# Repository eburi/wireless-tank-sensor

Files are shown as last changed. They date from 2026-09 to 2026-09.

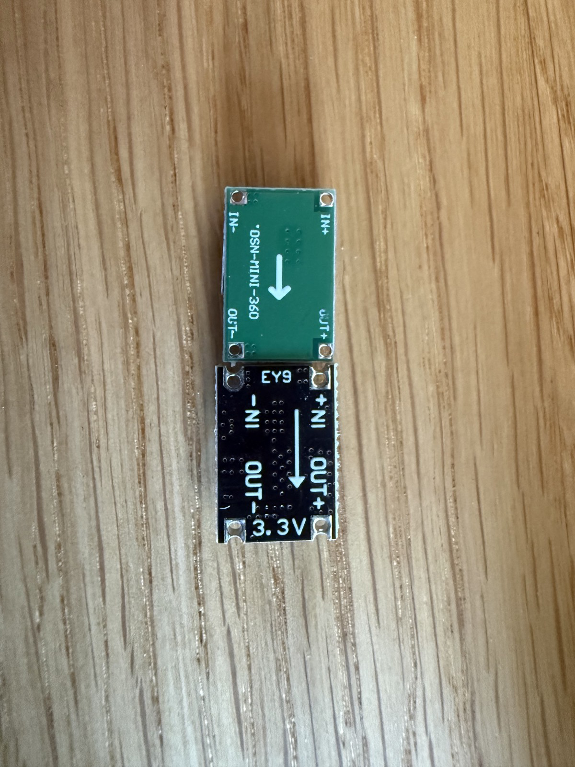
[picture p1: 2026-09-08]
hardware/kali-tank-sensor-v3/doc/dcdc-variants-side-by-side.jpg

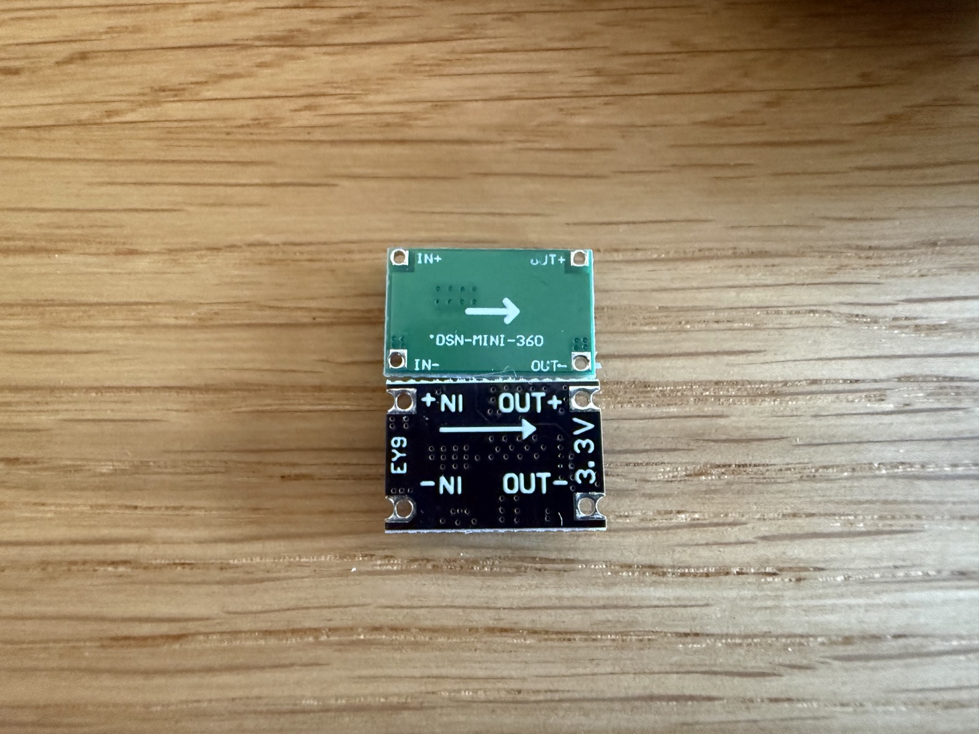
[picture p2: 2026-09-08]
hardware/kali-tank-sensor-v3/doc/dcdc-variants-stacked.jpg

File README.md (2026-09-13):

# 🚤 wireless-tank-sensor














A sealed, potted, maintenance-free **water tank level sensor** for boats (or caravans,
cabins, anything with a resistive tank sender and a 12 V bus). It runs on a
**Seeed XIAO ESP32-C3**, measures the plain old resistive float sender, works out the
level itself, and shouts the result at **Home Assistant** over **Bluetooth (BTHome v2)**.

You run **two wires** (12 V and ground) to the tank. That's it. No gauge, no Wi-Fi at
the tank, no app, no cloud. Everything else happens in the Home Assistant box you
already have on board.

> **TL;DR** — three ESPHome [external components](https://esphome.io/components/external_components/)
> (`bthome_beacon`, `tank_level`, `ota_beacon`) plus ready-to-copy example configs.
> Read on for the story, the wiring, and the lessons that cost me a night of sleep.

---

## 🧭 The backstory

When I bought the boat, she came with a set of tank sensors and a very confident
ship's manual. What she did *not* come with were the **analog gauges** those sensors
once fed — a previous owner had removed them at some point in the last geological era,
leaving behind a few dangling wires, a hole in the panel, and a gap in my
understanding of how much fresh water was actually left.

So for the first seasons the "fresh water level" was determined by a highly advanced
algorithm: *the pump starts sounding sad → tank is empty*. This works, in the sense
that a smoke alarm "works" as an oven timer.

Eventually I ripped out the corroded old senders and dropped in **cheap standard
resistive float senders** (~10 Ω to ~180 Ω, the kind every chandlery sells for the
price of a round of drinks). Then came the question: what to connect them to? Buying
new analog gauges felt like installing a fax machine. Buying a "smart" marine tank
monitor felt like paying for a fax machine with a subscription.

Meanwhile there was already a **Home Assistant** box on board, quietly collecting
temperatures, battery voltages and GPS fixes. It has Bluetooth. Bluetooth reaches the
tank locker. You can see where this is going.

The result is this repo: a tiny board that sits by the tank, needs only 12 V, sleeps
almost all the time, wakes up every ten seconds to measure the sender, and broadcasts
the level as a BTHome advertisement. Home Assistant picks it up like any other BTHome
gadget — no pairing, no integration to install, no IP address. The Wi-Fi radio is
switched off and only wakes for firmware updates, because on a boat the Wi-Fi is the
first thing you turn off to save power.

Now the fresh water tank shows up on the dashboard next to the batteries, the "tank
almost empty" sensor can nag me on my phone, and the pump has stopped sounding sad
unexpectedly. Mostly.

---

## ✨ What it does

| | |
|---|---|
| 📡 **BTHome v2 over BLE** | Home Assistant auto-discovers the sensor. Level (%), volume (L), raw sender resistance (Ω) and an *almost empty* problem flag, all in one 31-byte advertisement. |
| 😴 **Deep sleep duty cycle** | Wake → power the measurement chain → sample for ~2.5 s → advertise → sleep 10 s. The sender, the INA238 and its LED are completely unpowered in between. |
| 🧠 **Self-calibrating** | Learns the sender's real min/max resistance from the tank being filled and drained. Conservative: a new extreme needs five spaced observations, the least extreme one wins, the range never shrinks, spikes decay. Persisted to flash. |
| 🪣 **Tank content model** | Float senders have a dead zone at the bottom. Tell it total litres and how many litres the pump still delivers after the gauge reads 0 %, and it reports true content + a "you are now drinking the reserve" flag. Both numbers are editable in HA and stored on the device. |
| 🔒 **Wi-Fi off by default** | Turned on only in a 5-minute *maintenance window*: after a power cycle, or on request via a BLE trigger. If the boat Wi-Fi is gone, the node opens a fallback access point with a captive portal instead. |
| 🛰️ **BLE-triggered OTA** | A second ESP32 by the HA box advertises an iBeacon on demand (an HA switch). The sleeping sensor hears it on its next wake, opens Wi-Fi, and you flash it from the ESPHome dashboard. Potted in resin? Doesn't matter. |
| 🧱 **Fleet friendly** | One shared package, one ten-line file per tank, per-tank OTA targets, one API key for all. |
| 🔌 **Two wires** | 12 V in. Level out, through the air. |

---

## 🏗️ How it works

```mermaid
flowchart LR
    BUS[12 V bus] -->|PTC fuse, TVS, reverse diode| BUCK[buck module<br/>3.3 V]
    BUCK --> XIAO[XIAO ESP32-C3]
    XIAO <-->|I2C| INA[INA238<br/>current + voltage]
    RAIL[3.3 V] --> INA --> R2[series resistor] --> SENDER[float sender<br/>10–180 Ω] --> FET[logic-level MOSFET<br/>low-side switch] --> GND
    XIAO -->|GPIO3 MEAS_EN| FET
    XIAO -.->|BTHome adverts| HA[Home Assistant<br/>Bluetooth]
    BEACON[OTA trigger node<br/>second ESP32] -.->|iBeacon on demand| XIAO
    HA -->|switch| BEACON
```

The sender is just a variable resistor. The ESP switches a small current through it,
the INA238 measures that current and the voltage across the sender, and
`R = V / I`. No dependence on the supply rail, no dependence on the series resistor,
no ADC calibration. The `tank_level` component turns resistance into a percentage
using what it has learned about *your* sender, and `bthome_beacon` packs it into a
BTHome advertisement.

Because the node only listens for the OTA trigger while it is awake anyway, the
trigger costs nothing extra in power, and because it is a standard iBeacon frame
Home Assistant's iBeacon integration even shows the trigger as "present" while it is
on air — free proof the transmitter is transmitting.

---

## 🔩 Hardware

Two ways to build it. Both run the same firmware and the same example configs.

### Rev 3 — the carrier PCB (recommended)

A **55 × 52 mm four-layer carrier** in [hardware/kali-tank-sensor-v3/](hardware/kali-tank-sensor-v3/):
KiCad 10 project, DRC/ERC clean, gerbers, drill files, pick-and-place and BOM, ready for
a PCBWay-style order with SMT assembly. The XIAO and the buck module are hand-soldered
on top afterwards; four wire pads with strain-relief holes take the harness. See
[FABRICATION.md](hardware/kali-tank-sensor-v3/FABRICATION.md) for the order parameters,
assembly order and the things to check before first power-up.

| Part | Role | Approx. cost |
|---|---|---:|
| Seeed **XIAO ESP32-C3** + its **U.FL antenna** | Brain, BLE, deep sleep | €6 |
| **INA238** (bare MSOP-10, PCBWay places it) + **1 Ω 0.1 %** shunt | Measures chain current and sender voltage | €3 |
| **AO3400A** logic-level MOSFET | Low-side switch: sender is only powered while measuring | €0.10 |
| 100 Ω, 100 Ω, 100 kΩ, 2 × 4.7 kΩ | Current limit, gate series, gate pull-down, I2C pull-ups | pennies |
| 5–30 V → **3.3 V** buck module, 18 × 12 mm (mikroshop #2835 / DSN-MINI-360 class) | 12 V → 3.3 V | €1 |
| SS34, SMBJ16A, 200 mA PTC, 2 × 22 µF, 2 × 100 nF | Reverse-polarity, TVS, fuse, rail buffering | €1 |
| A resistive tank sender (any 10–180 Ω / 240–33 Ω / 0–190 Ω float sender) | The thing in the tank | €15–40 |

The whole thing runs on one 3.3 V rail: the buck feeds the XIAO's 3V3 pad through a
solder bridge (open it before plugging in USB), and the measurement chain runs from the
same rail through the INA238's own 1 Ω shunt. The I2C pull-ups hang on the switched
INA238 supply, so nothing back-feeds the chip while it sleeps unpowered.

### Rev 2 — the breadboard build

What ran on the bench and on the boat first: an INA238 *breakout* with its 15 mΩ shunt,
a BS170, a MINI-360 set to 5 V. Still valid, and the full wiring schema, part rationale,
bench findings and power budget for it live in [docs/hardware.md](docs/hardware.md).

| Part | Role | Approx. cost |
|---|---|---:|
| Seeed **XIAO ESP32-C3** + its **U.FL antenna** | Brain, BLE, deep sleep | €6 |
| **INA238** breakout (with onboard 15 mΩ shunt, I2C addr 0x40) | Measures chain current and sender voltage | €4 |
| **BS170** N-channel MOSFET | Low-side switch: sender is only powered while measuring | €0.20 |
| 150 Ω ¼ W, 100 Ω, 100 kΩ | Current limit, gate series, gate pull-down | pennies |
| **MINI-360** buck converter (set to 5.0 V) | 12 V → 5 V | €1 |
| 470 µF / 10 V, Schottky (1N5817), fuse | Rail buffering, USB back-feed protection, 12 V protection | €1 |

Wiring schema (rev 2)

### XIAO pins (both revisions)

| XIAO pin | GPIO | Goes to |
|---|---|---|
| 3V3 (rev 3) / 5V (rev 2) | — | Supply from the buck; rev 3 via solder bridge SB1 |
| GND | — | Common ground |
| D1 | GPIO3 | MOSFET gate via 100 Ω (`MEAS_EN`) |
| D4 | GPIO6 | INA238 SDA |
| D5 | GPIO7 | INA238 SCL |
| D10 | GPIO10 | INA238 supply (`VS`, switched — the chip and its pull-ups are off in deep sleep) |

The sender must be **two-wire / isolated** (both terminals free) for the low-side
switch to work. A hull-grounded single-wire sender needs high-side switching instead —
adapt the FET stage, the firmware doesn't care.

---

## 🚀 Installing

You need ESPHome (the Home Assistant add-on is fine) and a Home Assistant with a
Bluetooth adapter or an ESPHome Bluetooth proxy in range of the tank.

### 1. Grab the example configs

Copy the [`examples/`](examples/) folder into your ESPHome config directory:

```
esphome/
  packages/tank-common.yaml     everything shared: sensors, INA238, tank_level, BTHome, HA numbers
  packages/tank-sleep.yaml      the sleep cycle + BLE trigger matcher (includes tank-common)
  water-tank-1.yaml             one device file per tank — copy it for tank 2, 3, …
  water-tank-bench.yaml         same hardware, Wi-Fi always on, no sleep: for first hookup
  ota-trigger-beacon.yaml       the trigger node (second ESP32, lives next to HA)
  secrets.yaml.example          copy to secrets.yaml and fill in
```

The components are pulled straight from this repo:

```yaml
external_components:
  - source: github://eburi/wireless-tank-sensor
    components: [bthome_beacon, tank_level]   # the trigger node uses [ota_beacon]
    refresh: 1d
```

Pin to a release for reproducible builds: `source: github://eburi/wireless-tank-sensor@v1.0.0`.

### 2. Name your tank

A device file is four lines of substitutions and one include:

```yaml
substitutions:
  device_name: water-tank-1       # ESPHome node name / hostname
  friendly_name: "Water Tank 1"   # prefix of every HA entity
  bthome_name: Tank1              # BLE local name, max 9 characters (the advert is full)
  ota_target: "1"                 # 1–255, unique per tank — which OTA trigger it answers to

packages:
  sleep: !include packages/tank-sleep.yaml
```

### 3. Check the sender direction

`tank_level` maps **low resistance = empty** by default. Many European / VDO-style
senders are the other way round (~10 Ω full, ~180 Ω empty). If your gauge goes down
while you fill, set `invert: true` in `packages/tank-common.yaml`. (Or just look at the
learned-range sensors while filling; it becomes obvious very quickly.)

### 4. Flash and forget

1. Flash **`water-tank-bench.yaml`** first, over USB. It keeps Wi-Fi on and the
   measurement chain powered, so you can watch *Sender resistance*, *Chain current*
   and *Sender voltage* live and confirm the wiring before you pot anything.
2. Once the numbers make sense, OTA-flash **`water-tank-1.yaml`**. From now on the
   node sleeps and only advertises over BLE.
3. Home Assistant → *Settings → Devices & Services* will offer a new **BTHome** device
   called `Tank1`. Accept it. Done.

### 5. Let it learn, then tell it about litres

Calibration happens by itself: fill the tank, empty the tank, repeat a couple of times
over the season. The learned range shows up as **Learned R min / max** and is saved to
flash, so it survives power cuts and firmware updates.

For real litres, do the **pump test** once: drain until the level reads its floor, then
count the litres the pump still delivers until it starts gasping. Enter that as
**Tank reserve volume** and the tank capacity as **Tank total volume** — two `number`
entities on the ESPHome device in HA (visible while the maintenance window is open; they
are stored on the ESP). From then on the level is true content and **Tank volume** reports
litres.

---

## 🏠 What shows up in Home Assistant

Via **BTHome** (always, over Bluetooth, no Wi-Fi involved):

| Entity | BTHome object | Meaning |
|---|---|---|
| `sensor.tank1_moisture` (HA may add a MAC suffix) | moisture (%) | Tank level. Yes, "moisture" — BTHome has no "tank level" object and moisture is a percentage. Rename it, nobody will know. |
| `sensor.tank1_volume` | volume (0.1 L) | Litres in the tank, once total/reserve are set |
| `sensor.tank1_count` | count (uint16) | Raw sender resistance × 10 (diagnostic; 1234 = 123.4 Ω) |
| `binary_sensor.tank1_problem` | problem | **Almost empty** — float on its bottom stop, you're drinking the reserve |

Via the **ESPHome native API** (only while Wi-Fi is on, i.e. in the maintenance window
or on the bench variant): the raw INA238 readings, *Sender resistance*, *Learned R min /
max*, the *Measurement path* and *INA238 power* switches, and the two litre `number`s.

---

## 🛰️ Updating firmware without touching the thing

The sensor is meant to be potted in resin inside a locker you never want to open
again, so it must be updatable without physical access — but it also keeps Wi-Fi off.
Two ways in:

- **Power cycle.** A cold boot always opens a **5-minute maintenance window**: Wi-Fi on,
  API on, continuous measurement. Flash from the ESPHome dashboard inside that window.
- **BLE trigger.** Flash a second ESP32 with [`ota-trigger-beacon.yaml`](examples/ota-trigger-beacon.yaml)
  and park it near the HA box. It exposes one HA switch per tank (**OTA trigger tank 1**,
  **… tank 2**, **… all tanks**). Turn one on: it advertises an iBeacon for 4 minutes,
  the matching sensor hears it on its next wake, opens its maintenance window, and you
  flash it. The switch turns itself off; a 6-minute firmware backstop makes sure the
  beacon never advertises forever (which would make every sensor open Wi-Fi on every
  wake — that's why ESPHome's built-in `esp32_ble_beacon` couldn't be used: it has no
  runtime off switch).

- **No Wi-Fi at all?** Every example carries a fallback **access point + captive portal**.
  If a node cannot join the configured Wi-Fi within a minute of switching the radio on, it
  opens a WPA2 access point named after the device (`water-tank-1`, …), protected by
  `wifi_ap_password` from `secrets.yaml`. Join it, and the captive
  portal lets you enter new credentials or upload a firmware file — still no screwdriver.

> **Why not transmit from the HA host's own Bluetooth?** Tried it. On Home Assistant OS
> the Bluetooth integration owns the adapters and BlueZ refuses to register an
> advertisement (`org.bluez.Error.Failed`), even on an idle second adapter. A €6 ESP32 is
> cheaper than fighting BlueZ, and it doubles as a Bluetooth proxy.

> **The trigger format is a contract between two firmwares.** If you change the UUID,
> major or minor, reflash *both* ends. A sensor on an old build silently ignores the new
> trigger, and you will spend an evening wondering why. Ask me how I know.

---

## 🧪 The components

All three are plain ESPHome external components under [`components/`](components/).

### `bthome_beacon`

Non-connectable BLE advertiser producing a BTHome v2 service-data frame (UUID `0xFCD2`).
Objects are emitted in ascending id order as BTHome requires: packet id, `almost_empty`
(problem, `0x26`), `level` (moisture, `0x2F`), `count` (`0x3D`, value × 10), `volume`
(`0x47`, 0.1 L). Re-advertises once per second with the current sensor states.

```yaml
bthome_beacon:
  device_name: "Tank1"          # ≤ 9 chars if all four objects are used
  level: tank_level_cal         # sensor, % (required)
  count: sender_resistance      # sensor, × 10 → uint16 (optional)
  volume: tank_volume           # sensor, L (optional)
  almost_empty: tank_almost_empty   # binary_sensor (optional)
```

### `tank_level`

Resistance in, level out. Median-of-5 input window (kept in RTC memory so it spans
wake cycles), conservative learned min/max with NVS persistence that only ever learns
from a full-window median, EMA smoothing across deep-sleep cycles, and implausible
readings (outside `plausible_min`/`plausible_max`, NaN) hold the last good level
instead of publishing garbage. Optional volume model.

```yaml
tank_level:
  id: tank_model
  source: sender_resistance     # raw Ω sensor
  seed_min: 3.0                 # assumed range until enough is learned
  seed_max: 183.0
  invert: false                 # true if low resistance = full
  plausible_max: 250            # Ω; readings above are faults (default 400)
  level: { name: "Tank level" }
  volume: { name: "Tank volume" }
  almost_empty: { name: "Tank almost empty" }
  learned_min: { name: "Learned R min" }
  learned_max: { name: "Learned R max" }
```

Runtime setters `set_total_volume(l)` / `set_reserve_volume(l)` are what the two HA
`number` entities in the example call, and `reset_calibration()` is behind the
**Reset calibration** button: the learned range never shrinks on its own, so press it
after swapping the sender or whenever a bad range got in, then move the float through
its full travel a few times.

### `ota_beacon`

iBeacon transmitter with a runtime on/off and a safety timeout. Fixed major `0x4B4F`
("KO"), minor `0x54<target>` ("T" + tank number, 0 = all tanks). The sensor matches on
major/minor because those are byte-order unambiguous in ESPHome's iBeacon parser; the
UUID is only for Home Assistant's iBeacon integration to display.

```yaml
ota_beacon:
  id: trigger
  uuid: c0a1b2c3-d4e5-4f60-8172-8394a5b6c7d8
  safety_timeout: 6min
# then from a switch/automation:  id(trigger).start(1);  id(trigger).stop();
```

---

## 🧯 Lessons learned (so you don't have to)

- **The XIAO ESP32-C3 has no on-board antenna.** None. The U.FL pigtail is not optional.
  Without it the radio still "works" at bench range — BTHome reached a Raspberry Pi two
  metres away at −98 dBm, one dB above the noise floor — which is exactly why it went
  unnoticed while I debugged the OTA trigger firmware on *both* ends for a whole night.
  Attaching the antenna took the signal to a healthy −75 dBm. Glue the antenna down
  before potting; the connector pops off.
- **Check your MOSFET pinout with a meter.** My batch of "BS170"s had a mirrored
  S-G-D pinout. Installed per datasheet they conduct permanently through the body diode.
  The *path-off ≈ 0 mA* check on the bench catches this in ten seconds.
- **INA238 conversion time must fit the update interval.** `adc_time × averaging × 3
  channels` longer than `update_interval` means ESPHome's driver restarts the conversion
  every cycle and never publishes a value. 1052 µs × 128 at 1 s works; 4120 µs × 128
  does not.
- **The breakout's I2C pull-ups ride on its VIN.** At 5 V they idle at 5 V, which the
  ESP32-C3 does not appreciate. Feeding the breakout's VIN from a 3.3 V GPIO fixes the
  levels *and* makes the whole breakout (LED included) switch off in deep sleep for free.
- **Float senders have a dead zone.** The float bottoms out with litres still in the
  tank. Measure it once with the pump, tell the firmware, and stop lying to yourself
  about "0 %".
- **The first sample after switching the sender on is a lie.** The INA238 converts bus
  voltage and shunt current one after the other. Switch the measurement path on between
  the two and you get the resting rail voltage divided by the real current: sender plus
  about 130 Ω. On a sleeping node that happens at the same instant every wake, and the
  calibration happily learned 300 Ω as "full" from five of those. Hence the two-second
  settle gate in the example config, the full-window rule in `tank_level`, and the
  `plausible_max` option.
- **Verify a module's pad map against a photo of its bottom face, not its silkscreen
  logic.** The first carrier footprint grouped the buck's four corner pads by polarity
  (IN+ and IN− at opposite ends). The real module groups them by side: the long pitch
  separates IN from OUT, the short pitch separates + from −. Built as drawn it would have
  put 12 V backwards across the input and shorted the output to ground. Two photos and a
  meter, before ordering, are cheaper than five dead boards.
- **The first board layout is a third empty.** Rev 3.0 came out at 80 × 55 mm because the
  input chain and the buck formed one long row with the MCU beside it. Stacking the buck
  over the MCU and moving the analog block next to the wire pads gave 55 × 52 mm with the
  same circuit and shorter sender traces. Look at the empty regions before you order.
- **A 31-byte advertisement fills up fast.** Four BTHome objects plus a name leave nine
  characters for the name. Keep it short.

---

## 🗂️ Repo layout

```
components/
  bthome_beacon/    BTHome v2 advertiser
  tank_level/       self-calibrating level + volume model
  ota_beacon/       switchable iBeacon OTA trigger
examples/           ready-to-copy ESPHome configs (see Installing)
hardware/
  kali-tank-sensor-v3/  rev 3 carrier PCB: KiCad 10 project, gen_sch.py / gen_pcb.py
                        (the board is generated from source), gerbers + drill + CPL + BOM,
                        FABRICATION.md with order parameters and pre-power-up checks
docs/
  hardware.md       full hardware plan, wiring, rationale, bench notes, power budget
  wiring-schema.svg
  concept.md        the original design brief
.github/workflows/  CI compiles every example against the components in the repo
```

---

## 🤝 Contributing

Issues and PRs welcome — especially reports of other senders, other boards, or a
cleverer way to get litres out of a float. If you build one, I'd love a photo of your
tank locker. Fair winds.

## 📜 License

[MIT](LICENSE). Built for the sailing yacht *Kali*; no boats were harmed in the making
of this firmware, though one MOSFET was.

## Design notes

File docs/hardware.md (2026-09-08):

# Hardware — XIAO ESP32-C3 + INA238 tank sensor

Implementation plan for the sensor described in
[concept.md](concept.md), built from the
parts on hand. Target: the fresh water tank on my boat (Kali), VDO-style two-wire **isolated** sender,
European range **~10 Ω … ~180 Ω**. Polarity on Kali's sender: **low Ω = empty**
(firmware `invert: false`) — the rev-1/2 header claiming 10 Ω = full was wrong.

> **Rev 2 (2026-09-01):** adapted to the actual INA238 breakout (MRS190A) which has a
> 15 mΩ shunt and screw terminals on board — the external 2.2 Ω shunt is dropped — and to
> a belief that the XIAO's 3V3 pad was not available: the whole measurement path now
> runs from the 5 V rail. (That belief was a mistake — corrected 2026-09-05, the pad is
> free. The 5 V chain is kept anyway: more current through the 15 mΩ shunt means better
> INA238 resolution.) Includes a mandatory I2C level check before first hookup.

## Rev 3 (2026-09-08) — decisions taken

Design freeze for a manufactured carrier PCB (PCBWay, qty 5). Decided in review:

| Area | Rev 2 | Rev 3 | Why |
|---|---|---|-----|
| Rail | 5 V (XIAO LDO drops to 3.3) | **3.3 V single rail** | Skips the LDO drop; one rail for everything |
| Converter | MINI-360, socketed | **mikroshop #2835 module on pads** (5–30 V in, 3.3 V fix, 3 A, 18×12 mm, ~1 mA no-load, CHF 1.12) | 100 on hand, re-orderable, spec'd. A placed low-Iq buck (LM5165, ~10 µA) saves ~8.8 Ah/yr — not worth PCBA setup at qty 5 |
| INA238 | MRS190A breakout, 15 mΩ onboard shunt | **Bare INA238AIDGSR placed by PCBWay + chosen shunt** | Frees the shunt value; drops the breakout stack height and its 1–2 mA power LED — both matter under resin |
| Shunt | 15 mΩ (measured ~17.3 mΩ, 15 % off) | **1 Ω, 0.1 %, low tempco** | Shunt signal 0.18–0.45 mV → 12–30 mV; error vs the ±5 µV offset drops from ~2–4 % to ~0.03 % |
| R2 | 150 Ω (5 V rail) | **100 Ω** | With 3.3 V and a 1 Ω shunt: 12–30 mA, shunt 12–30 mV (inside ±40.96 mV even with the sender shorted, 32.6 mV), node A 0.30–2.11 V |
| Switch FET | BS170 TO-92, mirrored batch, R_ds ≈ 3 Ω | **Logic-level SOT-23** (AO3400A / SI2302 class) | 3.3 V gate drive is marginal for BS170/2N7002; ~30 mΩ removes the offset that compressed the full-tank end |
| TVS | "consider SMBJ18A" | **SMBJ16A** | The module's absolute max is 30 V; SMBJ18A clamps at 29.2 V — no margin. SMBJ16A clamps at 26.0 V |
| XIAO | headers | **Flat-soldered to top-side pads** | Lies flat for potting; USB-C edge kept clear for pre-potting bring-up |
| USB safety | "never connect both" | **Solder bridge in the 3V3 feed**, silk `OPEN BEFORE USB` | The real risk is USB back-feeding through the module into the 12 V harness, not the LDO fight |
| I/O | breakout screw terminals | **Solder pads + through-hole strain relief** | Potted; only the 12 V and sender cables leave the resin, long enough to re-terminate several times |
| Sealing | — | **Fully potted, U.FL antenna routed out of the pour** | Epoxy over 2.4 GHz detunes and attenuates, and BLE OTA is the only way back into a sealed board |
| Sender polarity | doc said 10 Ω = full | **low Ω = empty** (`invert: false`) | Firmware was right; the header and expected-values table were wrong |

**Firmware, agreed alongside:** raise the baseline wake interval to minutes, with
**adaptive sampling** — a reading that moves beyond a threshold drops the node to fast
sampling for a few minutes to capture a whole fill curve, then relaxes. Fill events feed
a fueling mode that is the only path allowed to *lower* the learned full end, so ageing
or corroding wiring can be tracked out. Fixed long intervals alone cannot do this: three
consecutive readings at 5 min is 15 min, and a tank fill can be over by then.

### The "sender no longer reads as high" question — resolved (2026-09-08)

Checked against the bench HA's recorder (192.168.1.170). There is **no drift** and the
sender has not degraded; the apparent decline is the v1.1.0 settle-gate fix working.

Evidence from `home-assistant_v2.db`:

- **Current learned range is `learned_r_max = 167.130 Ω`, `learned_r_min = 4.494 Ω`** —
  learned at 14:28–15:09 UTC on 2026-09-07, i.e. *after* the calibration reset at 14:24–14:26
  (which cleared the artefact-inflated 300.03 Ω) and *after* the settle gate landed. So the
  ~170 Ω top is the **most recent** genuine full-travel measurement on record, not an old one.
- **Everything that ever read higher was the artefact.** The native sensor's hourly maximum
  at 2026-09-07 11:00 UTC was **772.68 Ω** against a ~167 Ω sender — squarely inside the
  232–772 Ω range documented for the pre-fix switch-on bug. Weekly BTHome daily maxima
  (221.3 / 262.7 / 274.6 / 298.9 / 300.4 / 371.9 Ω) are all sender value + ~130 Ω;
  e.g. 167.2 + 130 = 297.2 ✓, 91.4 + 130 = 221.4 ✓.
- **After the fix (~14:00 UTC 2026-09-07) no reading has exceeded the true sender value:**
  hourly maxima 167.54 → 116.83 → 91.88 → 91.90. The wild excursions stop dead at the fix.

The "connection improved" hypothesis does not fit either: a degrading connection *adds*
series resistance (readings go **up**), corroded joints do not spontaneously improve, and
the change coincides exactly with a firmware flash rather than with any wiring event. The
91.4 Ω and 116.8 Ω plateaus since then are float positions, not attempted maxima.

**Only loose end:** there has been no full-travel sweep since 14:00 UTC on 2026-09-07. One
sweep to the top confirming it still reaches ~167 Ω closes this completely.

**Still a valid future mechanism:** `learned_r_max` never shrinks by design, so if the top
*does* decline later through corrosion, the tank would read low when full — which is exactly
what the planned fueling-mode calibration path exists to correct.

### Recorder capability (bench HA, checked 2026-09-08)

No `recorder:` block in `configuration.yaml` → defaults (`purge_keep_days: 10`,
`commit_interval: 5`, everything recorded; DB 114 MB). **Sufficient, and no change needed:**

- `sensor.kalitank_3e82_count` carries `state_class: measurement`, so HA keeps **hourly
  long-term statistics forever** (confirmed: 153 hourly rows back to 2026-09-01).
- BTHome quantises to 0.1 Ω, but with ~150–200 recorded changes/hour the reading dithers
  across adjacent steps and the **hourly mean resolves to ~0.005 Ω** — e.g. the stable
  91.4 Ω plateau reads 91.3577 → 91.4007 across 16:00–20:00.
- **Caveat for any future drift hunt:** the diagnostic channels (`sender_voltage`,
  `chain_current`, `shunt_voltage`) are ESPHome *native-API* entities and are `unavailable`
  whenever the sleep firmware runs with Wi-Fi off. Since R = V / I, R alone cannot say
  whether V, I or the shunt gain moved — run drift tests on the **bench firmware**.
- **And test gain drift at high resistance, not shorted.** A multiplicative error scales with
  the reading: 0.05 % is 0.046 Ω at 91.4 Ω (easily seen) but 0.002 Ω at 4.5 Ω — 50× below one
  quantisation step. Shorting the sender only isolates *offset*/contact drift.

### DC/DC module footprint (measured 2026-09-08)

Module outline **18 × 12 mm**, four corner holes, pads solderable from the top; the
14.5 mm variant additionally has half-castellations on the edges.

| Variant | Hole pitch X | Hole pitch Y | Inset from 18 mm edge |
|---|---:|---:|---:|
| A (castellated edges) | 14.5 mm | 8.5 mm | 1.75 mm |
| B | 15.0 mm | 8.5 mm | 1.50 mm |

Both are accepted by **one set of four oblong SMD pads**, since only X differs and only
by 0.5 mm:

- Pad centres **Y = ±4.25 mm** (exact for both).
- Pads elongated in X, spanning **X ≈ 6.25 → 10.0 mm** either side of centre
  (~3.75 × 2.4 mm each). That covers hole centres at both ±7.25 and ±7.50 mm with
  annulus margin, and runs ~1 mm past the module's ±9.0 mm edge so an iron can reach the
  pad from the side as well as through the hole.
- No copper pour under the module apart from these four pads — the module's underside
  carries vias and silk, and only solder mask separates it from the carrier.
- IN− and OUT− are expected to be one net (non-isolated buck); the two left-hand pads
  therefore both land on GND. **Verify by continuity before layout is committed.**

> **✅ Corner pinout — checked and resolved 2026-09-08.** Photographs of the two
> variants side by side, both bottom face up (green `DSN-MINI-360` and black `EY9 3.3V`),
> show **identical pad maps**, and the size difference is negligible. Both read, on the
> bottom face:
>
> ```
>   IN+  ......  OUT+
>          -->
>   IN-  ......  OUT-
> ```
>
> So the **14.5/15.0 mm pitch separates IN from OUT**, and the **8.5 mm pitch separates
> + from −**. One footprint serves both variants, and the earlier rev-2 MINI-360 is
> pin-compatible with the 3.3 V part.
>
> **This check caught a real error in the first footprint**, which had grouped the pads
> by polarity (+ on one side, − on the other) rather than by function. Built that way the
> board would have applied 12 V backwards across the module's input *and* shorted OUT+ to
> ground — exactly the failure the gate existed to prevent.
>
> **The corrected mapping.** The labelled face is the *bottom*: it must face down onto the
> carrier because the inductor side has to face up. Seen from above it therefore mirrors
> left↔right; rotating 180° in-plane to keep IN on the left gives the footprint as drawn:
>
> | Footprint corner (viewed from above) | Module pin |
> |---|---|
> | top-left | IN− |
> | bottom-left | **IN+** |
> | top-right | OUT− |
> | bottom-right | **OUT+** |
>
> Silkscreen on the carrier reads `IN+ = LOWER LEFT` as a build-time reminder. Still worth
> a 30-second continuity check that IN− and OUT− really are one net (non-isolated buck)
> before the first power-up, since the footprint ties both to the ground plane.
>
> Evidence photographs:
> [`../hardware/kali-tank-sensor-v3/doc/dcdc-variants-side-by-side.jpg`](../hardware/kali-tank-sensor-v3/doc/dcdc-variants-side-by-side.jpg)
> and [`.../dcdc-variants-stacked.jpg`](../hardware/kali-tank-sensor-v3/doc/dcdc-variants-stacked.jpg).

**Production should use the fixed 3.3 V variant.** The adjustable one depends on a cheap
trimpot that cannot be reached once the board is potted and can drift with vibration and
temperature — acceptable on the bench, not inside resin.

### The board (2026-09-08) — [`hardware/kali-tank-sensor-v3/`](../hardware/kali-tank-sensor-v3/)

KiCad 10 project, **DRC 0 errors / 0 unconnected, ERC 0 errors**. Gerbers, drill files,
pick-and-place and BOM are generated; see `FABRICATION.md` there for the PCBWay order
parameters and assembly order.

**55 × 52 mm, four layers** (F.Cu signal / In1 solid GND / In2 3V3 / B.Cu signal).
The first routed pass was 80 × 55 mm and only about 30 % populated: the 12 V chain and
the buck formed one 54 mm row with the XIAO beside it instead of below it. Compacted
2026-09-08 (rev 3.1). PCBWay prices both sizes in the same ≤ 100 × 100 mm tier, so the
gain is purely mechanical — enclosure and potting volume.
Four rather than two is a deliberate change: on two layers +3V3, NODE_A and the I2C
pair form a topological knot that needs a via maze to resolve, and the plane pair
removes the two largest nets (GND, 14 nodes; +3V3, 6 nodes) from the routing problem
altogether. It also puts a solid ground plane directly under the INA238 and under the
switching regulator, which is the right thing for a mixed-signal board. At qty 5 the
extra fab cost is small next to the PCBA setup already being paid.

Layout decisions that carried the routing:

- **Buck in the top-right corner, XIAO directly under it.** The buck's right-hand
  proud pads end at the board edge, the easiest possible iron access. The XIAO's top pad
  row has 7 mm to the module body; its bottom row faces only C2/C3/SB1.
- **XIAO rotated 270°** — USB-C flush on the right board edge (2.5 mm margin), signal
  pins on two horizontal rows. Pads stand 1.1 mm proud of the module outline, so all 14
  are iron-reachable and nothing routes under the module.
- **Analog block next to the sender pads it serves.** Moved as a rigid group, so the
  planar taps and the shared VS_INA bus are unchanged; NODE_A and NODE_B are ~20 mm
  shorter than in the first pass. MEAS_EN runs on the top layer with no vias; SDA/SCL
  hop to the bottom layer once each to cross the VS_INA bus.
- **INA238 rotated 90°** — its top row reads VS, GND, VBUS, IN−, IN+ left to right,
  matching the left-to-right order of the measurement chain placed above it. The
  analog taps are therefore planar: no crossings and no vias in the sensitive path.
- **I2C pull-ups sit on the VS_INA (GPIO10-switched) rail**, not on +3V3. On the
  always-on rail they would forward-bias the INA238's input protection diodes while
  it is unpowered in deep sleep.
- Copper keepout under the XIAO (exposed thermal pad plus JTAG/battery pads
  underneath, separated only by solder mask) and around the four non-plated
  strain-relief holes.

`gen_sch.py` and `gen_pcb.py` regenerate the schematic and board from source, so the
design is reproducible rather than a binary blob.

### Gates before the order goes in

1. ~~Calipers on the #2835 module.~~ **Done 2026-09-08** — 14.5 and 15.0 mm corner pitch
   in X, 8.5 mm in Y; one set of oblong pads takes both. See the footprint section below.
2. **Real power numbers at the 12 V input** — *partially* addressed 2026-09-08. The duty
   cycle is confirmed at **~30 %** (~4.5 s active per ~15 s cycle) and the design is
   qualitatively low power, but the magnitudes still await a working meter: the 1 A
   channel is broken and the 10 A range cannot resolve milliamps. Re-measure with a
   series resistor read on the **voltage** range — method in the bench note below. Not a
   blocker for ordering; it is a blocker for *claiming a number*.
3. ~~Explain the reading drift.~~ **Resolved 2026-09-08 from HA's recorder — it was the
   switch-on artefact, not drift.** See below. No electronics change is implied and the
   PCB is unaffected.
4. **Antenna-in-resin range test** on one unit before pouring five.

## Parts used

| Ref | Part | Role |
|-----|---|---|
| U1 | Seeed XIAO ESP32-C3 | MCU, BLE, deep sleep |
| U2 | INA238 breakout "MRS190A" (addr 0x40) | Measures chain current (onboard 15 mΩ shunt `R015` between screw terminals VIN+/VIN−) and bus voltage |
| U3 | DSN-MINI-360 buck converter | 12 V boat bus → **5.0 V** (final build; bench runs from USB-C) |
| Q1 | BS170 N-channel MOSFET | Low-side switch: measurement path powered only while measuring |
| R2 | 150 Ω ¼ W | Current limit resistor — exact value uncritical (VBus measures after it) |
| R3 | 100 Ω | Q1 gate series resistor |
| R4 | 100 kΩ | Q1 gate pull-down (keeps path off in deep sleep / boot) |
| C1 | 470 µF / 10 V electrolytic | Bulk capacitor on the **5 V** rail (BLE TX bursts; final build) |
| D1 | Schottky diode, e.g. 1N5817/SS14 (**recommended, see note**) | Prevents back-feed into USB when powering via the VUSB pin |
| F1 | Fuse 0.5–1 A | 12 V feed protection (final build) |

Breakout facts (from the board silkscreen): 16-bit, max bus 0–85 V, max ±10 A,
I2C address 0x40 with A0/A1 solder jumpers, two Qwiic-style JST connectors, power LED.

> **The XIAO ESP32-C3 has no on-board antenna — the U.FL pigtail antenna is mandatory,
> on every board.** Without it the radio still "works" at bench range (Wi-Fi at −85 dB,
> BTHome reaching a Raspberry Pi 2 m away at −98 dBm, i.e. 1 dB above the floor), which
> is exactly why it went unnoticed: the M5 trigger failed for a whole evening while both
> firmwares were fine. Antenna on the beacon node alone took its signal from
> "one frame cached at −100 dBm" to a steady −72…−84 dBm at the Pi. Fix the antenna in
> place (hot glue / tape over the U.FL) before potting — it pops off easily.
The "Cut for Low-Side" solder jumper **ships open** on this board (bench-verified: no
continuity, VBus floats and reads 0 V) — the silkscreen is misleading; it's really
"bridge for high-side". Instead of bridging it, the **VBus header pad is wired directly
to node A** (R2/sender junction), which is the better measurement anyway.

## Architecture

```mermaid
flowchart LR
    BUS[12V battery bus\n10-15V] -->|F1 fuse| BUCK[MINI-360\nset to 5.0V]
    BUCK -->|5V + C1 470uF| XIAO[XIAO ESP32-C3\nVUSB pin]
    XIAO <-->|I2C GPIO6/7| INA[INA238 breakout\nonboard 15 mΩ shunt]
    FIVE[5V rail] -->|VIN+ screw| INA
    INA -->|VIN- screw| CHAIN[R2 150 Ω - sender]
    CHAIN --> Q1[BS170 low-side switch]
    Q1 -->|gate = GPIO3| XIAO
    XIAO -.->|BTHome BLE adverts| HA[Home Assistant\nBluetooth/BT proxy]
```

The measurement chain (`5 V → VIN+ → R015 (on breakout) → VIN− → R2 → sender → Q1 → GND`)
only conducts while GPIO3 drives the BS170 gate high. In deep sleep the gate is held low
by R4, so the chain draws nothing. The XIAO's 3V3 pad is **not used**.

## I2C logic level — checked: pull-ups sit at VIN

Bench measurement (2026-09-01): with VIN = 5 V the idle SDA/SCL level is **5 V** — the
breakout's pull-ups reference VIN, there is no onboard 3.3 V logic rail, and the
ESP32-C3 is not 5 V tolerant. Therefore the breakout's **VIN is powered from XIAO pin
D10 (GPIO10) at 3.3 V** instead of the 5 V rail:

- INA238 VS range is 2.7–5.5 V → runs fine at 3.3 V, and the pull-ups now idle at 3.3 V.
- Load is ~2–3 mA (INA238 + power LED + pull-up current) — trivial for a GPIO pad.
- **Only the thin VIN wire moves.** The measurement chain stays on 5 V: screw VIN+ is
  still fed from the 5 V rail — the INA238's shunt and VBus inputs tolerate up to 85 V
  independent of VS.
- Bonus: in deep sleep GPIO10 floats → breakout (LED included) is fully off; no
  shutdown-register handling needed.
- D10/GPIO10 chosen because it is unencumbered: not a strapping pin (GPIO2/8/9), not a
  JTAG pin with a reset pull-up (GPIO4–7), and otherwise free.

## Wiring schema

Wire colors below match the actual harness: **red** = 5 V, **black** = GND,
**yellow** = SDA, **blue** = SCL, **orange** = MEAS_EN gate.

Wiring schema (rev 2)

### Power supply (final build — the bench runs from USB-C instead)

```
BOAT 12V BUS                    MINI-360 (adjust to 5.0V BEFORE connecting anything!)
============                   ┌──────────────────┐
 +12V ───[F1 0.5–1A]────────── │ IN+         OUT+ │ ──►|── D1 ──┬──────────► XIAO VUSB pin
                               │                  │  (1N5817)   │
  GND ───────────────┬──────── │ IN−         OUT− │ ────────────┼──┬
                     │         └──────────────────┘             │  │
                     │                                     C1 ═╪═  │   470 µF/10 V
                     │                                          │  │   (+) to 5 V side
                     └──────────────────────────────────────────┴──┴──► GND
```

**Warnings**

- **C1 is rated 10 V — 5 V output side only, never the 12 V input.**
- Set the MINI-360 with a multimeter *before* wiring its output. Multi-turn pot,
  arbitrary factory setting.
- D1: the VUSB pin is directly on the USB 5 V net. Feed it through a Schottky so the
  converter can't back-feed the USB port; without a diode, **never connect USB and the
  12 V feed at the same time**.
- Consider a TVS (e.g. SMBJ18A) across the 12 V input for the potted production unit.

### Measurement path and I2C

```
 XIAO D10 (GPIO10, 3.3 V out) ─────────────────────────────────────────► breakout VIN
                                              (logic + I2C pull-ups; off in deep sleep)

 5 V rail (bench: XIAO VUSB pad, USB powered) ── red ──────► screw VIN+ ─┐
                                                                        │ R015 15 mΩ
                                                     (onboard shunt,    │ (on board)
                                                      INA238 measures I)│
                                                            screw VIN− ─┘
                                                                 │
                                                                [R2] 150 Ω
                                                                 │
                                                                 ●─ node A ◄── breakout VBus pad
                                                                 │             (jumper ships open —
                                                                 │              wire it here)
                                                                 │
                                                             ┌───┴────┐
                                                             │ SENDER │ 10–180 Ω two-wire
                                                             └───┬────┘ (bench: 200 Ω pot)
                                                                 │
                                                                 ●─ node B
                                                                 │ D
 XIAO D1 (GPIO3) ── orange ──[R3 100Ω]──● G                   BS170  Q1
                                        │                        │ S
                                       [R4 100k]                 │
                                        │                        │
 GND (black) ───────────────────────────┴────────────────────────┴── XIAO GND, breakout GND

 I2C:
 XIAO D4 (GPIO6) ── yellow ──► breakout SDA ┐  breakout has its own pull-ups —
 XIAO D5 (GPIO7) ── blue ────► breakout SCL ┘  do the level check above first!
 A0/A1 jumpers open = address 0x40 · ALRT not connected
 VBus: internally tied to the shunt via the "Cut for Low-Side" jumper — leave it,
       do not wire the VBus pad.
```

### XIAO ESP32-C3 pin map

| XIAO pin | GPIO | Connects to | Function |
|---|---|---|---|
| VUSB | — | 5 V rail: screw VIN+ (final: D1 cathode, C1 +) | Supply |
| GND | — | Common ground bus | |
| D1 | GPIO3 | R3 → Q1 gate (orange) | `MEAS_EN` — high = measurement path on |
| D4 | GPIO6 | Breakout SDA (yellow) | I2C data |
| D5 | GPIO7 | Breakout SCL (blue) | I2C clock |
| D10 | GPIO10 | Breakout VIN (red) | `INA_POWER` — 3.3 V supply for the breakout, off in sleep |

GPIO3 is deliberately chosen: not a strapping pin (GPIO2/8/9 are), no JTAG pull-up
quirk (GPIO4–7 have one at reset), and in deep sleep it floats so R4 holds Q1 off.
The 3V3 pad is unused.

## Design rationale

### Resistance measurement: R = V / I

The INA238 measures the chain current through the onboard 15 mΩ shunt and the voltage
at **node A** (the VBus pad is wired there, since the board's VBus jumper ships open).
The firmware computes:

```
R_sender + R_ds(on) = V_bus / I
```

No dependence on rail accuracy or on R2's value; supply sag during BLE activity doesn't
matter. With `MEAS_EN` off, node A rests at ≈ 5 V (no current through R2) — normal.

### Why tolerances (mostly) don't matter

The self-calibration (learned min/max resistance → 0–100 %) absorbs:

- **Shunt tolerance** — pure gain error on I, cancels in the percentage mapping.
- **Q1's R_ds(on)** (≈2–5 Ω at V_GS 3.3 V) — a near-constant offset, cancels in the
  mapping.
- **R2** doesn't appear in the math at all with node-A sensing — its tolerance is
  irrelevant; it only sets the current window.

### The small-shunt caveat (to verify on the bench)

15 mΩ at 15–31 mA gives only ~225–460 µV of shunt signal. Against the INA238's ±5 µV
offset spec that's a worst-case ~2–4 % level error, plus noise (heavy averaging is
configured). For a fresh-water gauge that's acceptable — but **bench task: check reading
stability**; if it disappoints, the lever is more current (smaller R2) before anything
drastic.

### Sizing R2 (150 Ω)

- Limits worst-case current (sender shorted) to `5 V / 153 Ω ≈ 33 mA` — safe for the
  rail and trivial for the BS170 (500 mA).
- Keeps the current window 15–31 mA over the sender range: decent shunt signal, ~140 mW
  peak in R2 (¼ W part, duty-cycled in production).

### INA238 configuration (firmware)

- ADC range **±40.96 mV** (max shunt signal here is < 0.5 mV — always the fine range).
- Long conversions + heavy on-chip averaging; firmware filters further across the 2–3 s
  measurement window. **Constraint (bench-learned):** the full conversion round
  (adc_time × averaging × ~3 channels) must finish inside the update interval, or the
  ESPHome driver restarts the conversion every cycle and never publishes — 1052 µs ×
  128 ≈ 0.4 s works with a 1 s interval; 4120 µs × 128 did not.
- Before deep sleep: drop GPIO10 — the breakout (INA238, pull-ups, LED) is then fully
  unpowered. No shutdown-register handling needed. I2C is open-drain, so the dead bus
  back-powers nothing.

### BS170 low-side switch

- Valid **because the sender is two-wire and isolated**. (A hull-grounded sender would
  need high-side switching instead.)
- **⚠️ Batch pinout warning (bench-verified 2026-09-01):** the BS170s on hand are
  mirrored — flat face toward you they are **S–G–D** (2N7000-style), not the datasheet's
  D–G–S. Installed per datasheet they conduct permanently through the body diode
  (~15 mA with the path off, ~0.66 V across the part). Correct install for this batch:
  **left leg → GND, middle → gate, right leg → node B.** Verify any batch with the
  path-off ≈ 0 mA check before potting.
- V_GS = 3.3 V vs. BS170 threshold spec 0.8–3.0 V: most parts fine, a high-threshold
  specimen may be marginal. **Bench check:** sender terminals shorted → displayed
  resistance ≤ ~5 Ω and stable; otherwise swap in another BS170.
- R4 guarantees the path is off during boot, deep sleep, and firmware crashes.

### Power budget (estimates — verify on the bench)

| State | Draw | Notes |
|---|---|---|
| Deep sleep, XIAO | ~44 µA @ 3.3 V | Seeed's figure for the C3 |
| Deep sleep, INA238 shutdown | < 10 µA | |
| Breakout "on" LED | ~1–2 mA while GPIO10 is high | Off in sleep automatically (GPIO-powered breakout) |
| Deep sleep, MINI-360 quiescent | **~0.5–2 mA @ 12 V** | Dominates! Measure it. |
| Active window (~2–3 s per 10 s) | ~25 mA avg, BLE peaks ~80 mA | C1 buffers the peaks |

Rough average: ~3 mA @ 12 V ≈ **70 mAh/day ≈ 2 Ah/month** — acceptable. Biggest levers:
MINI-360 quiescent draw (a low-Iq buck like Pololu D24V5F5 is a drop-in swap), the LED,
wake interval, and active-window length.

**Option: buck to 3.3 V and feed the XIAO's 3V3 pin directly.** The XIAO's on-board LDO
drops 5 → 3.3 V linearly, so while awake it burns (5 − 3.3) V × I_awake — roughly a third
of what the ESP itself uses (≈ 30 mW during the active window, ≈ 10 mW averaged over the
duty cycle, ≈ 1 mA at 12 V, ≈ 25 mAh/day). Real but second-order: the wake interval and
the buck's own quiescent draw each move more. Trade-offs if done: the 5 V rail disappears,
so the measurement chain runs at 3.3 V (currents drop to ~10–20 mA → coarser INA238
resolution; halve R2 to ~68 Ω to compensate — the learned calibration is in Ω and does
not care); disconnect the 3.3 V feed while USB-programming (two supplies in parallel on the
3V3 net); no diode in the 3.3 V line (the C3 needs ≥ 3.0 V under Wi-Fi bursts); keep C1 on
the 3.3 V rail. Feasible on the bench unit as well — its 3V3 pad is free.

## Bench test plan

Bench power: USB-C into the XIAO; the 5 V rail is the VUSB pad. Fake sender: fixed
resistors (10 / 47 / 100 / 180 Ω) or a 200 Ω pot.

**Bench status (2026-09-01):** steps 1–5 done. Findings so far: the FET batch has a
mirrored pinout (see warning above); the onboard shunt behaves like ~17.3 mΩ instead of
15 (readings ~15 % low — pure gain error, absorbed by calibration; a 150 Ω test sender
reads ~130 Ω); USB bench rail measures ~5.27 V via VBus with the path off. Gating
verified: 0 mA off / 20.6 mA on. **Firmware milestone 1 done:** BTHome advertising
works end-to-end — HA discovered "KaliTank" over the Pi's Bluetooth and receives level
(moisture %) and resistance (count ×0.1 Ω). **Milestone 2 done (bench-verified):** the
duty-cycled sleep firmware reports over BTHome at regular intervals with Wi-Fi off,
values track resistor changes, and the INA238 is visibly powered only during
measurement windows. Remaining: accuracy sweep with the real sender, fault cases,
stability.

**Bench status (2026-09-05):** M5 verified end-to-end once the beacon node got its
antenna (see the XIAO note above). The unit now runs from 12 V through the MINI-360 at
~5 V; the quantitative power measurement (sleep vs. active, at the 12 V side) is still open.

**Bench status (2026-09-08) — supply current on the 3.3 V side (⚠️ not usable as it stands):**
Measured at the DC/DC converter's **3.3 V output**, bench DMM on its **10 A range** (the
meter's 1 A range is broken):

| State | Reading |
|---|---:|
| Awake, measurement window (chain on) | 1.11 mA |
| Awake, before/after the measurement window | ~0.30 mA |
| Deep sleep | 0.001 mA |

These numbers are recorded for continuity, but **none of them can carry a design decision**:

- **Wrong side of the converter.** The number this design needs is the draw at the
  **12 V input**, which is dominated by the converter's own quiescent current — by
  definition invisible from its 3.3 V output.
- **Wrong range.** A 10 A range shunt is on the order of 10 mΩ; 1 mA across it is ~10 µV,
  at or below the meter's noise floor. `0.001 mA` is not a measurement of anything —
  Seeed's own figure for a sleeping ESP32-C3 is ~44 µA, 44× higher.
- **The awake figure is physically implausible.** An ESP32-C3 awake draws ~20–25 mA with
  the radio idle and peaks ~80 mA on BLE TX. 1.11 mA is roughly 20× too low.

What survives: sleep draw is far below awake draw, and there is an intermediate (~0.3 mA
indicated) awake-but-not-measuring state. Ratios only, no absolute values.

**To get real numbers**, measure in the **12 V feed**:

- *Sleep state:* 100 Ω in series (1 mA → 100 mV, easy on any DMM; the 0.1 V drop out of
  12 V is harmless while asleep).
- *Active window:* 1–10 Ω in series with a scope across it — this shows the BLE TX peaks
  and the true duty-cycle shape, which a meter's average hides.
- Or settle both in one shot with a µA-capable tool (Nordic PPK2 or equivalent).

Two numbers are needed before a PCB revision can claim a power improvement: **converter
quiescent at 12 V with the XIAO asleep**, and **average input current over a full
wake + sleep cycle**.

**Bench measurement (2026-09-08, second attempt) — 12 V input side, rev-2 bench build.**
Now on the correct side of the converter, but still on the meter's **10 A range** (the
1 A channel is still broken), so the magnitudes remain unusable. Observed cycle:

| Phase | Reading | Duration |
|---|---:|---|
| Measurement window | 0.640 mA | ~4.5 s |
| Deep sleep | 0.096–0.1 mA | ~10 s |
| Intermediate (≈5 s after sleep begins) | 0.230 mA | brief |

**What is usable: the timing.** The cycle is ~15 s with roughly 4.5 s active — a **~30 %
duty cycle**, matching the v1.1.0 firmware (2 s settle gate + measurement window, then
~10 s sleep). That is measured from *when* the readings change, not from their size, so
it stands regardless of the meter's accuracy. It confirms the duty cycle is the dominant
energy term, ahead of both the converter's quiescent draw and the 5 V→3.3 V rail change.

**What is not usable: the magnitudes.** For this rev-2 build (5 V rail, 150 Ω chain,
breakout INA238) the expected figures at 12 V are ~0.3–1 mA asleep (the module's own
datasheet claims "<1 mA" no-load) and ~20–25 mA in the active window. The readings are
20–35× below that. A simple scale error was ruled out: it would preserve the ratio, but
the measured active/sleep ratio is **6.7** where the hardware should give ~30. Both
endpoints compressed toward each other is the signature of a reading dominated by offset
and noise, which is what a 10 A range does when its few-milliohm shunt sees ~20 mA
(well under 100 µV).

**Conclusion that is safe to draw:** qualitatively the design *is* low power — there is
no continuous high-current path, the meter never read high, and the duty cycle behaves as
designed. From the component figures the estimated average is **≈7 mA at 12 V ≈ 60 Ah/yr**
at the current ~15 s cycle, falling to **≈1 mA ≈ 9 Ah/yr** once the wake interval goes to
minutes — at which point the converter's quiescent current becomes the whole budget. On a
boat with any charging at all, both are small. **The exact figure remains unmeasured** and
should not be quoted as fact until the meter is repaired.

**Method for the re-measurement** (sidesteps the broken mA channel entirely — use the
voltage ranges, which work): put a resistor in series with the 12 V feed and measure the
voltage across it. 100 Ω for the sleep state (1 mA → 100 mV; the 0.1 V drop is harmless
while asleep), 10 Ω for the active window (20 mA → 200 mV). A scope across the 10 Ω is
better still — it shows the BLE bursts and the true duty-cycle shape instead of an average.

> The meter's "USB sharing" is a **screenshot export**, not a data stream: it enumerates
> as an Artery AT32 mass-storage device (serial 07C5C47A8991, 14.7 MB) mounted under a
> volume name of 11 non-breaking spaces, containing only empty `LOGO/`,
> `Screenshot file/` and `Screenshot simple file/` folders. There is no serial port and
> no live logging — pressing the meter's save button drops a display image into
> `Screenshot file/`, which can then be read off the mounted volume.

1. ~~I2C level check~~ done: pull-ups sit at VIN → breakout VIN rewired to D10 (3.3 V).
2. ~~VBus jumper~~ checked: ships open (VBus read 0 V) → **wire the VBus pad to node A**.
3. **Power**: breakout LED on (fed from D10), 5 V at VUSB / screw VIN+.
4. **I2C**: flash the bench firmware (see [../examples/](../examples/)), check the log finds 0x40.
5. **Switch**: `MEAS_EN` off → ≈ 0 mA, VBus ≈ 5 V (node A rests at the rail); on →
   current flows, VBus drops to the sender voltage.
6. **Accuracy**: compare displayed resistance per the table below and a multimeter;
   verify stability (small-shunt caveat).
7. **Fault cases**: open sender → ≈ 0 mA, VBus → ~5 V → fault; shorted sender →
   ≤ ~5 Ω, VBus ≈ 0.1 V (validates Q1).
8. **Power draw** at 12 V (once the MINI-360 stage is added) in active and sleep states.

Expected values (**rev 2** — 5.0 V rail, R2 = 150 Ω, R_ds(on) ≈ 3 Ω, VBus at node A, R = V/I):

| Sender R | Chain current | VBus (node A) | Displayed R |
|---:|---:|---:|---:|
| 10 Ω (empty) | ~30.7 mA | ~0.40 V | ~13 Ω |
| 47 Ω | ~25.0 mA | ~1.25 V | ~50 Ω |
| 100 Ω | ~19.8 mA | ~2.04 V | ~103 Ω |
| 180 Ω (full) | ~15.0 mA | ~2.74 V | ~183 Ω |
| open | ~0 mA | → ~5 V | invalid → fault |
| short | ~32.7 mA | ~0.10 V | ~3 Ω (= R_ds) |

A consistent ~3 Ω surplus over the true resistor value is Q1's R_ds(on) — correct, and
absorbed by calibration.

## Firmware roadmap

- **Phase 1 — bench bring-up (now):** plain ESPHome over Wi-Fi, no deep sleep. Validates
  wiring, INA238 readings, the resistance math, and how much filtering/averaging the
  real sender needs. Config lives in [../examples/](../examples/) and was provisioned on
  a HAOS bench Raspberry Pi.
- **Phase 2 — production firmware (in ESPHome, milestone by milestone; port to ESP-IDF
  only if the framework fights back):**
  1. **BTHome advertising, no sleep:** small custom external component (BTHome v2 is one
     BLE service-data blob) added to the bench firmware; verify the HAOS Pi
     auto-discovers it over Bluetooth while Wi-Fi debugging still works.
  2. **Duty cycle** (implemented: `examples/packages/tank-sleep.yaml`, sharing
     `packages/tank-common.yaml` with the bench variant): `deep_sleep` +
     `wifi: enable_on_boot: false`. Timer wake → measure ~2.5 s → a few BTHome
     advertisements with the fresh value → all off → sleep 10 s. **Cold boot
     (power-cycle) opens a 5-minute maintenance window** — Wi-Fi + continuous
     measurement, i.e. bench behavior — used for OTA (and later as the commissioning
     mode on the boat); going back to the bench firmware is power-cycle + OTA within
     the window. Still to measure: real consumption at 12 V (needs the MINI-360 stage).
  3. **Self-calibration + persistence** (implemented: `components/tank_level`):
     median-filtered input, learned min/max with conservative acceptance (a new
     extreme needs 5 observations spaced ≥ 30 s / one per wake, the least extreme
     candidate wins, the range never shrinks, stale candidates decay), seed range
     3–183 Ω used until the learned span reaches 25 Ω, EMA smoothing across wakes in
     RTC memory, implausible readings (< 1 Ω / > 400 Ω / NaN) hold the last good
     level. Calibration + last level persist to NVS flash (writes only on accepted
     extremes or ≥ 2 % level moves — flash-wear-safe) and survive power cycles *and*
     firmware variant swaps. Kali's sender: **low R = empty** → direct mapping
     (`invert` option exists for VDO-style senders). To wipe learned calibration:
     USB-flash with flash erase, or bump the preference key in `tank_level.cpp`.
  4. **Tank content model** (implemented; values pending the on-site pump test): float
     senders have a bottom dead zone — Kali's sender saturates at ~4.5 Ω over its
     lowest cm and sits above unmeasured tank volume. `reserve_volume` (liters the pump
     still delivers after measured 0 %) and `total_volume` rescale the published level
     to true content (bottoms out at the reserve fraction instead of a false 0 %), add
     a **Tank volume** sensor in liters (BTHome volume object, 0.1 L) and a **Tank
     almost empty** problem-class binary (BTHome binary object) that trips when the
     float sits on its bottom stop and the reserve drains unmeasured. Defaults 0/0 =
     previous behavior. On-site procedure: drain until the gauge reads its floor, count
     liters until the pump struggles → that's `reserve_volume`.
  5. **BLE-triggered OTA** — both ends implemented; end-to-end test pending hardware.
     The trigger is a standard **iBeacon** frame (project UUID, major 0x4B4F "KO",
     minor 0x54<target>). While awake the sensor scans (~94 % listen duty) and matches
     on major/minor via ESPHome's native iBeacon parser (byte-order unambiguous — the
     UUID is only for display); a match opens the same 5-minute maintenance window as
     a cold boot (Wi-Fi + OTA + live measurement), then it sleeps again.
     **Transmitter: a second XIAO** (`examples/ota-trigger-beacon.yaml`, custom
     `components/ota_beacon`) — required because ESPHome's built-in `esp32_ble_beacon`
     has no runtime on/off and would advertise forever, making the sensor open Wi-Fi
     every wake. Idle by default; an HA switch advertises for 4 min with a 6 min
     firmware backstop. **Bonus of the iBeacon choice: HA's iBeacon integration shows
     the trigger as present while it's on air** — free proof it's transmitting.
     **Bench finding (2026-09-04): the HA host's own radio cannot be the transmitter** —
     HAOS BlueZ refuses `RegisterAdvertisement` (`org.bluez.Error.Failed`) even on the
     idle hci1, because HA's Bluetooth integration owns the adapters; `btmgmt` isn't
     shipped, and freeing the adapter would kill BTHome reception. The beacon node
     doubles as an ESPHome Bluetooth proxy if Kali's HA needs better reception.
- **Phase 3 — helpers & install:** OTA-trigger transmitter (HA-host BLE if milestone 4
  proves it, else a second XIAO), optionally an ESPHome Bluetooth proxy, enclosure +
  potting (LED removed, correct-pinout FET verified), install on the fresh water tank.

## Open questions

- Reading stability with the 15 mΩ onboard shunt at 15–30 mA (small-shunt caveat).
- BS170 specimen threshold check.
- MINI-360 real-world quiescent current at 12 V.
- Sampling time needed per cycle for a stable reading with sloshing.
- Sender wiring run on Kali: may warrant 100 nF across the sender terminals / ESD
  clamping at node A for the potted unit.

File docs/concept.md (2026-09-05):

# Concept — XIAO ESP32-C3 BLE tank sensor

## Purpose

The tank sensor is a sealed, maintenance-free node based on a Seeed
Studio XIAO ESP32-C3. It measures a conventional resistive tank sender,
derives the tank level locally, and reports the result to Home Assistant
using BTHome BLE advertisements.

The design deliberately does not depend on Wi-Fi for normal operation.
On a boat, the Wi-Fi infrastructure may be switched off to save energy.
Wi-Fi is therefore used only when a firmware update is required.

The completed sensor may be installed in a sealed enclosure and fully
potted in resin. Normal operation and firmware maintenance must
consequently require no physical access.

## Hardware Concept

The node consists of:

-   XIAO ESP32-C3
-   I2C voltage/current measurement device
-   Measurement circuit for the variable-resistance tank sender
-   Switchable measurement electronics where useful to reduce standby
    consumption
-   Boat power supply interface
-   No buttons, connectors, or other physical controls required after
    installation

The tank sender itself is treated simply as a variable resistor. The
ESP32 derives its resistance from the measured voltage and current.

## Normal Operating Cycle

The sensor spends most of its time in deep sleep.

Approximately every 10 seconds it wakes and performs one measurement
cycle:

1.  Wake from deep sleep.
2.  Power or enable the measurement circuitry if it was switched off.
3.  Read voltage and current repeatedly over I2C for approximately 2--3
    seconds.
4.  Calculate the sender resistance.
5.  Filter the measurements to suppress electrical noise, sender noise,
    and short-term effects caused by vessel motion and liquid sloshing.
6.  Validate the result and reject implausible readings, open circuits,
    short circuits, and transient outliers.
7.  Update the learned sender range where appropriate.
8.  Map the filtered resistance to a tank level between 0 and 100%.
9.  Transmit the resulting level using BTHome BLE advertisements.
10. Briefly scan for the dedicated BLE OTA trigger.
11. If no OTA trigger is detected, persist changed long-term state when
    necessary and return to deep sleep.

Several BTHome advertisements should be transmitted during the wake
period rather than relying on a single BLE packet. Missing an individual
measurement is acceptable because tank level changes slowly.

## Automatic Tank Calibration

The sensor requires no tank-specific configuration.

It learns the useful resistance range of the installed sender over time.
Persistent state includes at least:

-   Learned minimum resistance
-   Learned maximum resistance
-   Relevant calibration confidence/state
-   Last known valid tank level
-   Diagnostic/fault state where useful

The learning algorithm must not simply accept every all-time minimum and
maximum. New extrema should be sanitized and accepted conservatively.

The implementation should:

-   Filter measurements before using them for calibration.
-   Reject electrically implausible values.
-   Reject isolated spikes and unrealistic changes.
-   Require repeated or sufficiently stable observations before
    accepting significant new extrema.
-   Expand the learned range conservatively.
-   Avoid automatically shrinking the learned range because normal
    operation may not visit empty or full for long periods.
-   Persist learned calibration across deep sleep and power cycles.

The resulting filtered resistance is mapped directly onto the learned
range to produce a clamped 0--100% tank-level value. The mapping
direction can be automatically handled or fixed according to the sender
characteristics.

Broad initial assumptions may be used before both real extrema have been
observed, but normal operation should progressively improve the
calibration without user intervention.

## BTHome and Home Assistant

The primary BLE output is a standard BTHome percentage measurement
representing tank level.

Home Assistant can receive this through its native Bluetooth/BTHome
support, directly or through Bluetooth proxies. No tank-specific Home
Assistant integration is required.

The normal production payload should remain small. The essential value
is:

-   Tank level: 0--100%

Development firmware may additionally advertise diagnostic information
such as raw resistance or fault state.

All tank interpretation and calibration belongs on the sensor. Home
Assistant should not need to understand the sender resistance or
calibration algorithm.

## BLE-Triggered OTA Mode

Wi-Fi is completely disabled during normal operation.

During every normal wake cycle, the XIAO briefly scans for a predefined
BLE advertisement representing an OTA request.

The OTA trigger is a unique advertisement signature controlled by the
system. A dedicated BLE-capable device near Home Assistant, such as
another XIAO ESP32-C3, can repeatedly transmit this trigger when an
update is requested.

The tank sensor does not need to receive the trigger immediately.
Because it wakes approximately every 10 seconds, the OTA trigger
transmitter should advertise continuously for long enough that the
sensor encounters it during one of its scan windows.

When the trigger is detected, the tank sensor:

1.  Cancels the normal return to deep sleep.
2.  Enables Wi-Fi.
3.  Connects to the configured boat Wi-Fi network.
4.  Starts the OTA service.
5.  Remains awake for a defined OTA maintenance window.
6.  Accepts a firmware update if one is supplied.
7.  Reboots after a successful update.
8.  Returns to normal low-power operation if the OTA window expires
    without an update.

The OTA implementation should include a safe recovery mechanism so that
a failed application startup does not permanently prevent subsequent
firmware updates.

## OTA Trigger Transmitter

A separate BLE node associated with Home Assistant can provide the OTA
trigger.

Its behavior is simple:

1.  Remain idle during normal operation.
2.  When an OTA update is requested, repeatedly transmit the predefined
    BLE OTA-trigger advertisement.
3.  Continue advertising for several minutes or until the target tank
    sensor becomes reachable over Wi-Fi.
4.  Stop advertising after the update operation or timeout.

The exact mechanism by which Home Assistant controls this transmitter is
independent of the tank-sensor protocol and can be implemented later.

## Power Strategy

The fundamental power-management rule is:

**BLE is the always-available communication mechanism; Wi-Fi is a
temporary maintenance mechanism.**

The sensor therefore avoids periodic Wi-Fi association or update
polling. In particular, it does not wake every minute merely to check
whether an update exists.

Normal power consumption consists primarily of:

-   Deep-sleep current
-   Approximately one measurement period every 10 seconds
-   Short BTHome advertising bursts
-   A short BLE scan for the OTA trigger

The comparatively expensive Wi-Fi radio is activated only after an
explicit BLE OTA request.

Further optimization can reduce the active period once practical
measurements establish how long the sender must be sampled to obtain a
sufficiently stable tank-level estimate.

## State Model

The firmware can be represented by four principal states:

`DEEP_SLEEP -> MEASURE -> BLE_ADVERTISE/SCAN -> DEEP_SLEEP`

When an OTA trigger is received:

`BLE_SCAN -> WIFI_OTA -> REBOOT -> normal operation`

This keeps the normal execution path deterministic, short, and
independent of any external network infrastructure.

## Design Principles

-   No physical interaction required after installation.
-   Suitable for a fully sealed and resin-potted enclosure.
-   Wi-Fi-independent normal operation.
-   Home Assistant integration through standard BTHome rather than
    custom HA code.
-   Self-calibrating resistive sender with persistent learned limits.
-   Aggressive use of deep sleep.
-   BLE-triggered, Wi-Fi-based remote firmware updates.
-   Graceful operation when Home Assistant, Bluetooth receivers, or boat
    Wi-Fi are temporarily unavailable.
-   Sensor intelligence remains local so tank measurement continues to
    work independently of the rest of the vessel infrastructure.

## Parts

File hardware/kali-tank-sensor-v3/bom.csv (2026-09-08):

Reference | Qty | Value | Footprint | Manufacturer PN | Source | Notes
U1 | 1 | Seeed XIAO ESP32-C3 | kali:XIAO-ESP32C3_TopSolder | 113991054 | Seeed | HAND-SOLDER after delivery. Flash BEFORE soldering down.
U2 | 1 | INA238AIDGSR | Package_SO:MSOP-10_3x3mm_P0.5mm | INA238AIDGSR | LCSC C2868250 / DigiKey | PCBWay places. Consign to avoid markup.
U3 | 1 | 3.3V buck 5-30V 3A | kali:DCDC_Module_18x12_4pad | mikroshop 2835 | mikroshop.ch | HAND-SOLDER. VERIFY CORNER PINOUT FIRST.
R1 | 1 | 1R 0.1% 25ppm | Resistor_SMD:R_0805_2012Metric |  |  | Current-sense shunt. Precision matters here.
R2 | 1 | 100R 1% | Resistor_SMD:R_0805_2012Metric |  |  | Chain current limit
R3 | 1 | 100R | Resistor_SMD:R_0805_2012Metric |  |  | Q1 gate series
R4 | 1 | 100k | Resistor_SMD:R_0805_2012Metric |  |  | Q1 gate pull-down (holds path off in sleep)
R5 | 1 | 4k7 | Resistor_SMD:R_0805_2012Metric |  |  | SDA pull-up to VS_INA (switched)
R6 | 1 | 4k7 | Resistor_SMD:R_0805_2012Metric |  |  | SCL pull-up to VS_INA (switched)
C1 | 1 | 100nF X7R 16V | Capacitor_SMD:C_0805_2012Metric |  |  | INA238 VS decoupling
C2 | 1 | 22uF X5R 10V | Capacitor_SMD:C_1206_3216Metric |  |  | 3V3 bulk at the regulator
C3 | 1 | 22uF X5R 10V | Capacitor_SMD:C_1206_3216Metric |  |  | 3V3 bulk at the MCU (BLE TX bursts)
C4 | 1 | 100nF X7R 50V | Capacitor_SMD:C_0805_2012Metric |  |  | 12V input HF decoupling
D1 | 1 | SS34 | Diode_SMD:D_SMA | SS34 |  | Reverse-polarity block. 40V > TVS clamp.
D2 | 1 | SMBJ16A | Diode_SMD:D_SMB | SMBJ16A |  | TVS, 26.0V clamp. NOT SMBJ18A - 29.2V is too close to the module's 30V max.
F1 | 1 | PTC 200mA hold | Resistor_SMD:R_1206_3216Metric |  |  | Fuses the TVS failure mode (TVS fails short)
Q1 | 1 | AO3400A | Package_TO_SOT_SMD:SOT-23 | AO3400A |  | Logic-level. NOT BS170/2N7002 - marginal at 3.3V gate.
SB1 | 1 | Solder bridge | kali:SolderBridge_2pad |  |  | Normally CLOSED. OPEN before connecting USB.
J1-J4 | 4 | Wire pad | kali:WirePad_StrainRelief |  |  | Solder pads, 2.2mm strain-relief hole below each

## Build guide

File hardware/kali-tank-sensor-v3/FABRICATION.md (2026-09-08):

# Kali tank sensor rev 3 — fabrication package

Generated 2026-09-08 (rev 3.1 layout: 55 × 52 mm, compacted from the first 80 × 55 mm
pass). **Verified: KiCad DRC 0 errors, 0 unconnected items; ERC 0 errors.**

## PCBWay order parameters

| Setting | Value |
|---|---|
| Layers | **4** |
| Size | 55 × 52 mm |
| Quantity | 5 |
| Thickness | 1.6 mm |
| Min track / spacing | 0.25 mm / 0.15 mm (inside the standard 6 mil tier) |
| Min hole | 0.35 mm |
| Surface finish | ENIG (recommended — marine, and better for the 0.5 mm-pitch INA238) |
| Solder mask | any; **green reads best under conformal coat** |
| Assembly | SMT top side only, **excluding U1 and U3** (hand-soldered after delivery) |

Gerbers, drill files and the pick-and-place CSV are in `gerbers/`.

Four layers rather than two: it gives a solid ground plane (In1) directly under the
INA238 and the switching regulator, and a 3V3 plane (In2). On two layers the +3V3,
NODE_A and I2C nets form a knot that needs a via maze to resolve — the plane pair
removes the two largest nets from the routing problem entirely.

## Before powering the first board

1. ~~Verify the DC/DC module's corner pinout.~~ **Done 2026-09-08.** Both variants
   (green `DSN-MINI-360` and black `EY9 3.3V`) have an identical pad map and negligible
   size difference. On the bottom face: **IN+ top-left, OUT+ top-right, IN− bottom-left,
   OUT− bottom-right** — the 14.5/15.0 mm pitch separates IN from OUT, the 8.5 mm pitch
   separates + from −. The footprint is drawn for the module mounted label-side-down and
   viewed from above, which mirrors that: **IN+ is the LOWER-LEFT pad** (also on the
   silkscreen). One footprint takes both variants.
2. **Still confirm IN− and OUT− are one net** (non-isolated buck) with a meter — the
   footprint ties both to the ground plane.
3. Use the **fixed 3.3 V** variant in production. The adjustable one depends on a
   trimpot that is unreachable once potted and can drift.

## Assembly order

1. PCBWay assembles all SMD parts except U1 and U3.
2. **Flash the XIAO before soldering it down** — after assembly, USB needs SB1 opened.
3. Solder U3 (DC/DC module) onto the four oblong pads. They accept both the 14.5 mm
   and 15.0 mm corner pitch and stand ~1 mm proud of the module so an iron reaches them.
4. Solder U1 (XIAO) flat onto its land pattern. Pads stand 1.1 mm proud of the module
   outline — solder from the side, no standoffs needed.
5. Attach and secure the U.FL antenna **before potting**, and route the pigtail out
   of the pour.
6. Wires to J1–J4, each anchored through its 2.2 mm strain-relief hole.

## SB1

Normally **closed**, feeding the buck's 3.3 V into the XIAO's 3V3 pad. **Open it before
connecting USB** — otherwise USB power back-feeds through the module into the 12 V
harness. After potting, USB is unusable anyway and recovery is BLE-triggered OTA.

## Known-good design decisions worth not undoing

- `MSOP-10_3x3mm_P0.5mm` for the INA238, not KiCad's default TSSOP-10. The datasheet's
  DGS0010A drawing cites JEDEC MO-187 variation BA, which is the MSOP footprint.
- I2C pull-ups (R5/R6) go to **VS_INA**, the GPIO10-switched rail — not to +3V3.
  On the always-on rail they would forward-bias the INA238's input protection while
  it is unpowered in deep sleep.
- The 0.15 mm clearance rule exists only because the INA238's own MSOP land has
  0.15 mm pad gaps at 0.5 mm pitch. No track is narrower than 0.2 mm.

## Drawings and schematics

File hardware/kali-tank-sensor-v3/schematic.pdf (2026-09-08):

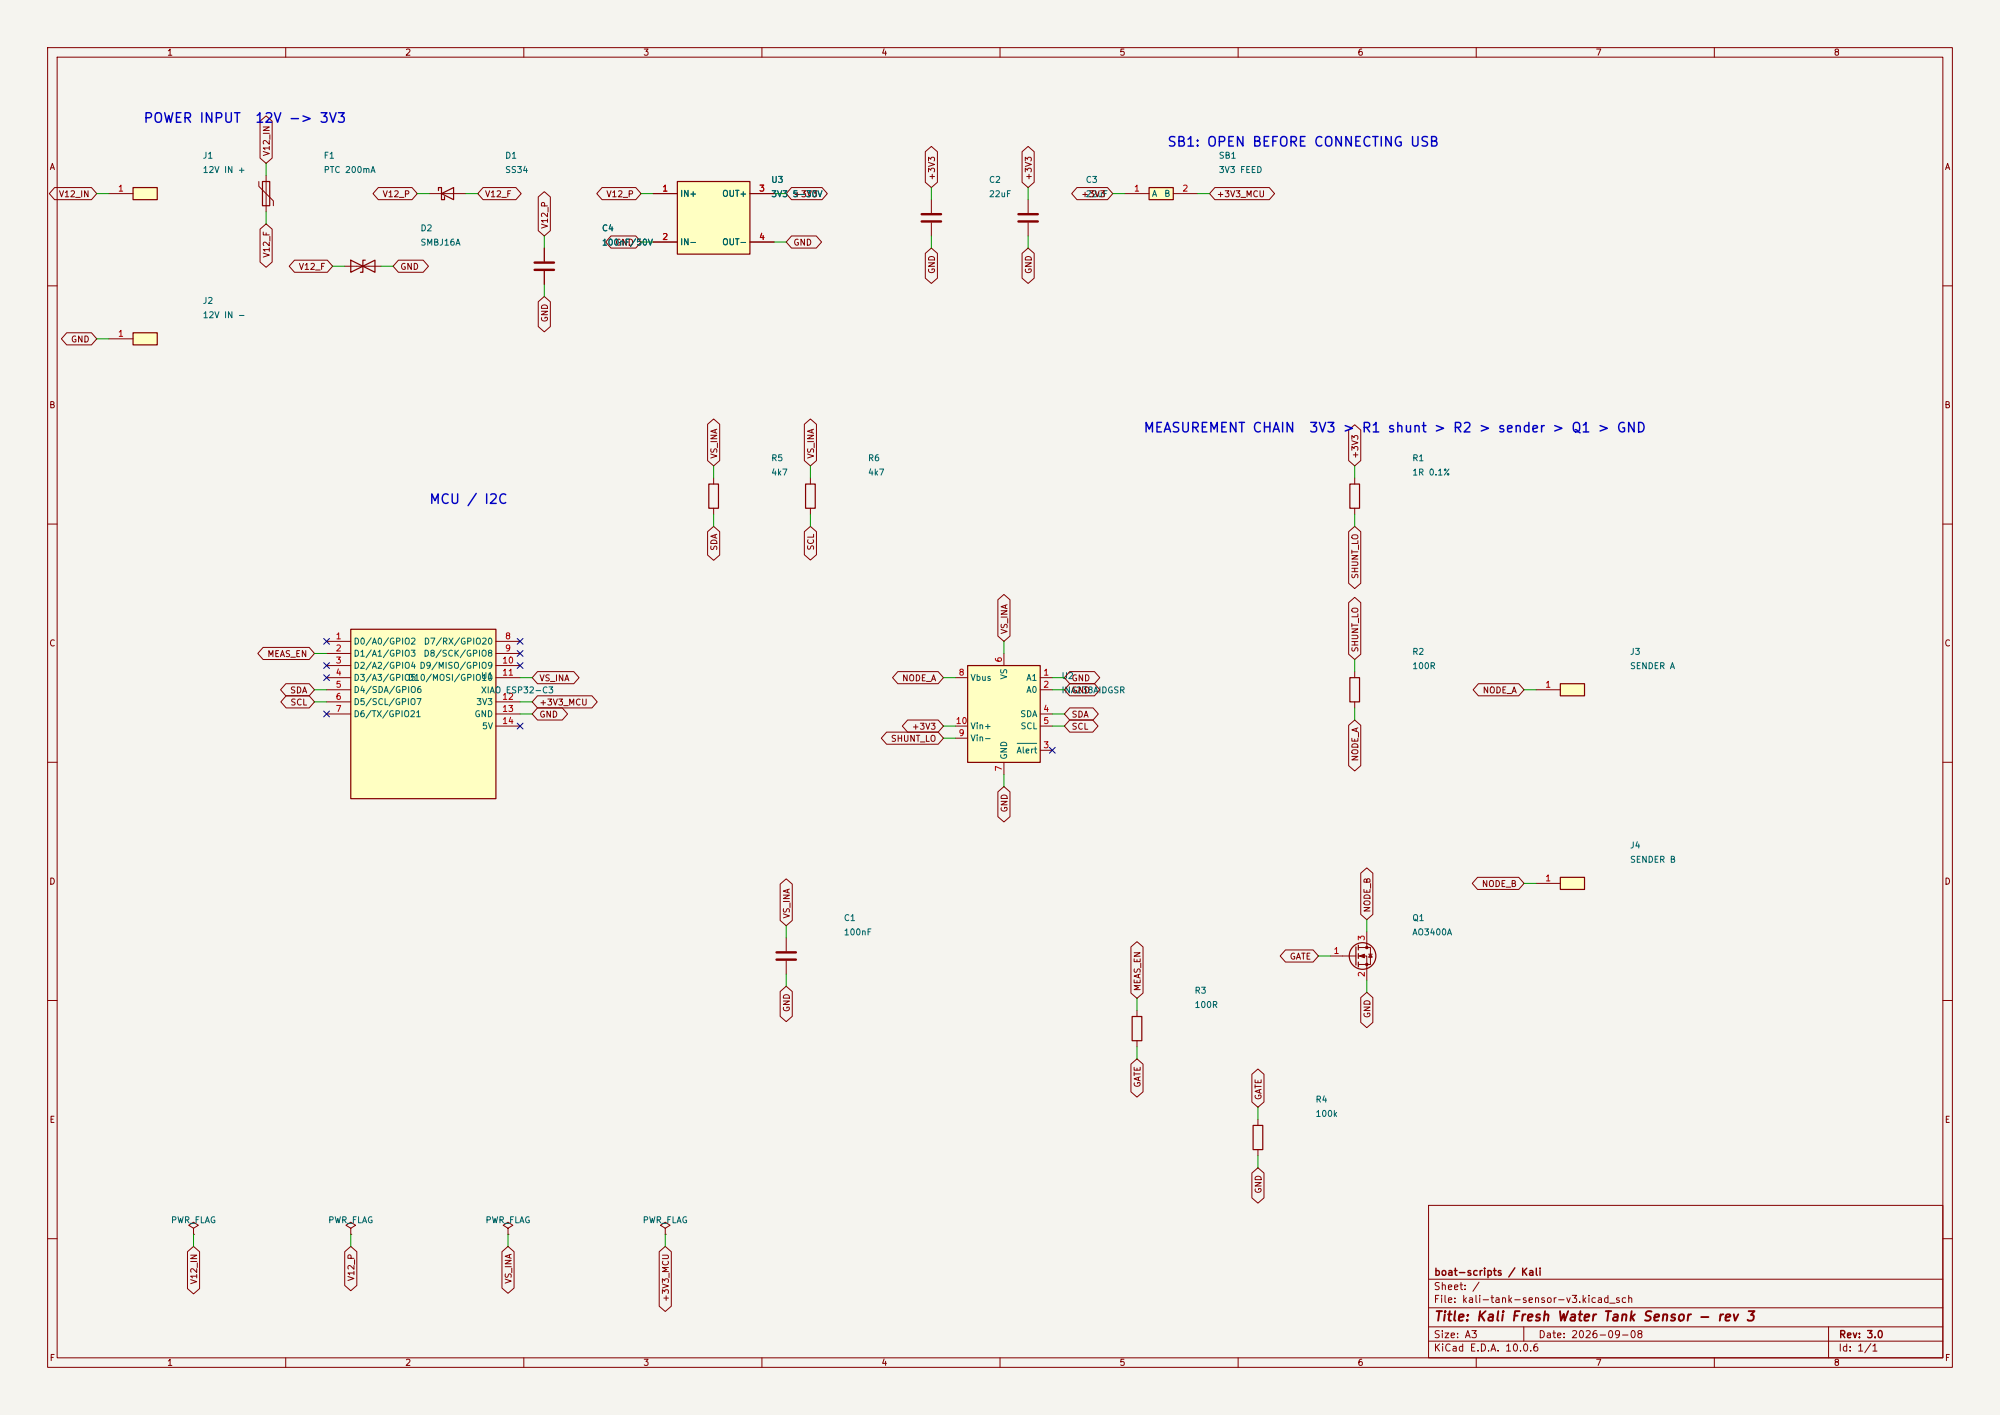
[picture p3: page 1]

SB1: OPEN BEFORE CONNECTING USB

MEASUREMENT CHAIN 3V3 > R1 shunt > R2 > sender > Q1 > GND

boat-scripts / Kali
Sheet: /
File: kali-tank-sensor-v3.kicad_sch
Title: Kali Fresh Water Tank Sensor - rev 3

Size: A3 | Rev: 3.0 | F Date: 2026-09-08
KiCad E.D.A. 10.0.6 | Id: 1/1

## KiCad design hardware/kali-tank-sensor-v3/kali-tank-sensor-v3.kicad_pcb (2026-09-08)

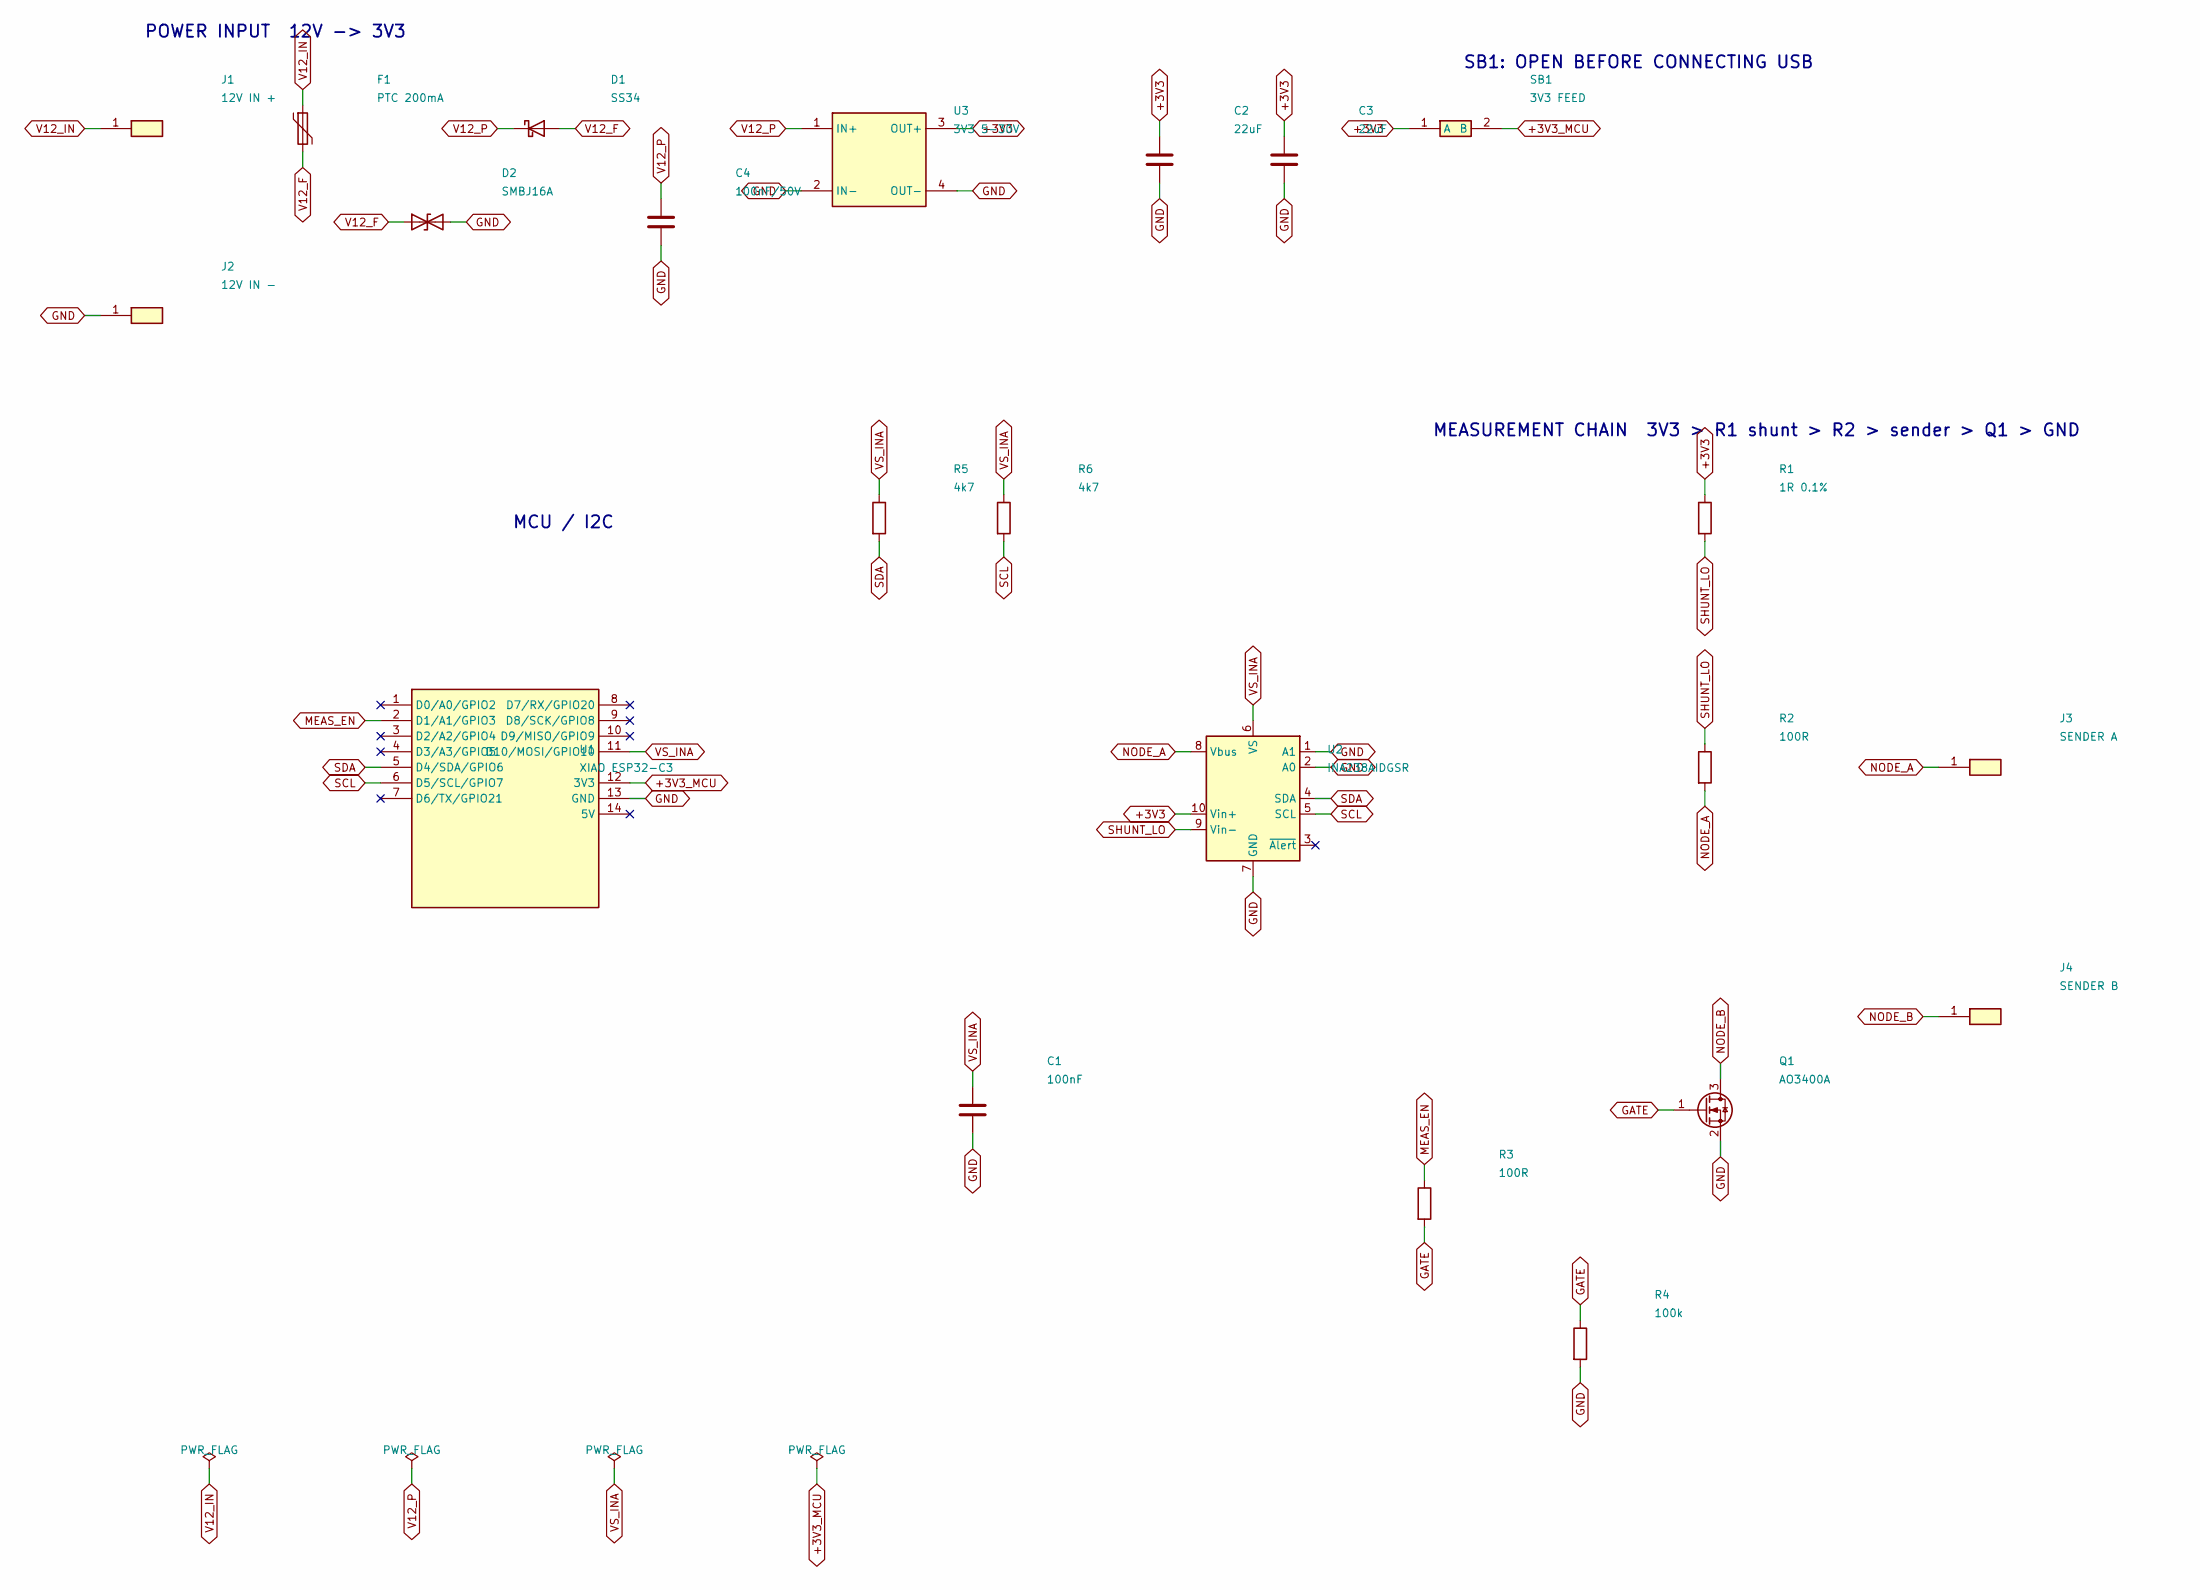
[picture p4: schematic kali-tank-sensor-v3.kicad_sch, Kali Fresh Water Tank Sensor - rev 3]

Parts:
C1: 100nF; C_0805_2012Metric
C2, C3: 22uF; C_1206_3216Metric
C4: 100nF/50V; C_0805_2012Metric
D1: SS34; D_SMA
D2: SMBJ16A; D_SMB
F1: PTC 200mA; R_1206_3216Metric
J1: 12V IN +; WirePad_StrainRelief
J2: 12V IN -; WirePad_StrainRelief
J3: SENDER A; WirePad_StrainRelief
J4: SENDER B; WirePad_StrainRelief
Q1: AO3400A; SOT-23
R1: 1R 0.1%; R_0805_2012Metric
R2, R3: 100R; R_0805_2012Metric
R4: 100k; R_0805_2012Metric
R5, R6: 4k7; R_0805_2012Metric
SB1: 3V3 FEED; SolderBridge_2pad
U1: XIAO ESP32-C3; XIAO-ESP32C3_TopSolder
U2: INA238AIDGSR; MSOP-10_3x3mm_P0.5mm
U3: 3V3 5-30V; DCDC_Module_18x12_4pad

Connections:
+3V3: C2.1, C3.1, R1.1, SB1.1 (A), U2.10 (Vin+), U3.3 (OUT+)
+3V3_MCU: SB1.2 (B), U1.12 (3V3)
GATE: Q1.1 (G), R3.2, R4.1
GND: C1.2, C2.2, C3.2, C4.2, D2.2 (A2), J2.1, Q1.2 (S), R4.2, U1.13 (GND), U2.1 (A1), U2.2 (A0), U2.7 (GND), U3.2 (IN-), U3.4 (OUT-)
MEAS_EN: R3.1, U1.2 (D1/A1/GPIO3)
NODE_A: J3.1, R2.2, U2.8 (Vbus)
NODE_B: J4.1, Q1.3 (D)
SCL: R6.2, U1.6 (D5/SCL/GPIO7), U2.5 (SCL)
SDA: R5.2, U1.5 (D4/SDA/GPIO6), U2.4 (SDA)
SHUNT_LO: R1.2, R2.1, U2.9 (Vin-)
V12_F: D1.2 (A), D2.1 (A1), F1.2
V12_IN: F1.1, J1.1
V12_P: C4.1, D1.1 (K), U3.1 (IN+)
VS_INA: C1.1, R5.1, R6.1, U1.11 (D10/MOSI/GPIO10), U2.6 (VS)

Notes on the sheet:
POWER INPUT 12V -> 3V3
MEASUREMENT CHAIN 3V3 > R1 shunt > R2 > sender > Q1 > GND
MCU / I2C
SB1: OPEN BEFORE CONNECTING USB

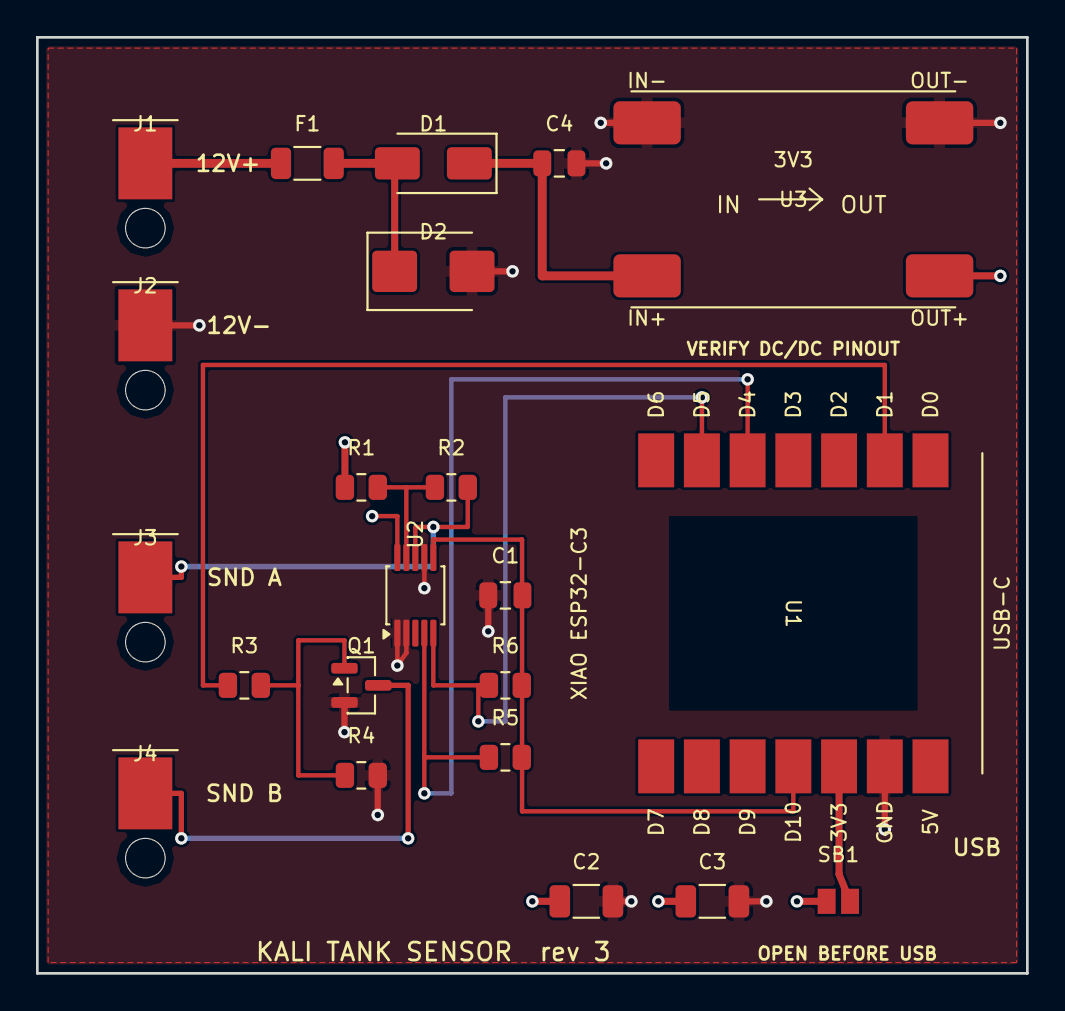
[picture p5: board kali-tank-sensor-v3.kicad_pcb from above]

Board: 4 copper layers, 55.0 x 52.0 mm, 22 parts (0 on the bottom side), 14 nets.

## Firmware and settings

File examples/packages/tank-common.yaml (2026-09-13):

# Shared package for every tank sensor. The device file sets the substitutions;
# nothing else differs between tanks (calibration is learned on the device, the
# litre figures are per-device "number" entities stored in NVS).
#
#   device_name    ESPHome node name / hostname, e.g. water-tank-1
#   friendly_name  prefix for every HA entity, e.g. "Water Tank 1"
#   bthome_name    BLE local name in the BTHome advert, max 9 chars (the frame is full)
#
# Wiring: see docs/hardware.md (XIAO ESP32-C3 + INA238 breakout + BS170 low-side switch).
esphome:
  name: ${device_name}
  friendly_name: ${friendly_name}

esp32:
  board: seeed_xiao_esp32c3
  framework:
    type: esp-idf

logger:
  logs:
    ina2xx: INFO   # the driver logs "Updating" / "Initiating new data collection" every second

api:
  encryption:
    key: !secret api_encryption_key   # one shared key for the whole fleet

ota:
  - platform: esphome
    password: !secret ota_password

# The custom components come straight from GitHub. Pin `ref:` to a tag if you
# want reproducible builds; `refresh` controls how often ESPHome re-fetches.
external_components:
  - source: github://eburi/wireless-tank-sensor
    components: [bthome_beacon, tank_level]
    refresh: 1d

# Fallback access point + captive portal (the ap: block sits next to the Wi-Fi
# credentials in the variant files). Only ever active while Wi-Fi is enabled and
# cannot connect, i.e. in a maintenance window on the sleeping firmware.
captive_portal:

esp32_ble:

# BTHome v2 advertising. HA's Bluetooth integration discovers the device natively;
# tank level arrives as BTHome "moisture" %, volume as "volume" (0.1 L), the raw
# sender resistance as "count" in tenths of an ohm, and "almost empty" as a
# problem-class binary sensor.
bthome_beacon:
  id: bthome
  device_name: "${bthome_name}"
  level: tank_level_cal
  count: sender_resistance
  volume: tank_volume
  almost_empty: tank_almost_empty

# Self-calibrating tank level. Learns the sender's usable resistance range
# conservatively (a new extreme needs 5 spaced observations, the least extreme
# candidate wins, the range never shrinks) and persists it to NVS flash, so it
# survives deep sleep, power cycles and firmware updates.
# Low resistance = empty → invert: false (default). Set invert: true for senders
# that read low when full (many VDO/European ones: ~10 Ω full, ~180 Ω empty).
tank_level:
  id: tank_model
  source: sender_resistance
  seed_min: 3.0     # broad assumptions until the learned span reaches 25 Ω
  seed_max: 183.0
  plausible_max: 250   # Ω; a 10–180 Ω sender never reads more — anything above is a fault
  invert: false
  # Tank content model: total/reserve litres come from the two "number" entities
  # below (editable in HA, persisted on the ESP), not from this config.
  level:
    name: "Tank level"
    id: tank_level_cal
  volume:
    name: "Tank volume"
    id: tank_volume
  almost_empty:
    name: "Tank almost empty"
    id: tank_almost_empty
  learned_min:
    name: "Learned R min"
  learned_max:
    name: "Learned R max"

# MEAS_EN — BS170 gate on D1/GPIO3. On = the measurement chain conducts.
# INA_POWER — the breakout's VIN is fed from D10/GPIO10 at 3.3 V because its I2C
# pull-ups ride on VIN. Both pins float in deep sleep: chain and breakout fully off.
# Switch-on settle gate. The INA238 converts bus voltage and shunt current one after
# the other; a sample whose bus voltage was converted just before the measurement
# path switched on (node A resting at the rail) but whose current was converted just
# after reads as sender + ~130 Ω. With a 1 s update and ~0.4 s conversions, anything
# published less than 2 s after switch-on may be such a straddle — drop it.
globals:
  - id: meas_on_ms
    type: uint32_t
    restore_value: no
    initial_value: '0'

switch:
  - platform: gpio
    pin: GPIO3
    id: meas_en
    name: "Measurement path"
    restore_mode: ALWAYS_OFF
    on_turn_on:
      - lambda: 'id(meas_on_ms) = millis();'
  - platform: gpio
    pin: GPIO10
    id: ina_power
    name: "INA238 power"
    restore_mode: ALWAYS_ON

i2c:
  sda: GPIO6   # D4
  scl: GPIO7   # D5
  frequency: 100kHz
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

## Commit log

2026-09-05 Initial release: ESPHome external components + example configs + README
    bthome_beacon, tank_level and ota_beacon as external components at the repo
    root (ESPHome's default path for github:// sources), generic example
    configs (shared packages, per-tank device file, bench variant, OTA trigger
    node), hardware/concept docs, MIT license, and a CI workflow that compiles
    every example against the components in the commit.
2026-09-05 ci: pin esphome/build-action to v8.1.0 (no floating major tag exists)
2026-09-07 examples: fallback AP + captive portal, ignore trigger frames during an open window
    - captive_portal on every example, with an open fallback AP named after the
    device (ap_timeout 1 min) so a node whose Wi-Fi is gone can still be reached
    during its maintenance window.
    - tank-sleep: only arm the OTA flag while duty-cycling and clear it when the
    window closes — frames heard during an open window used to queue a second
    window right after it.
2026-09-07 README: pin syntax is github://owner/repo@tag; describe the fallback AP + captive portal
2026-09-07 tank_level: never learn from switch-on artefacts; plausible_max; reset_calibration()
    The first sample after the measurement path switches on can pair a bus voltage
    converted before switch-on (node A at the rail) with a current converted after
    it, reading as sender + ~130 Ω. On a sleeping node this is the first sample of
    every wake, and calibration took exactly that sample as its one observation per
    boot — five wakes with the float at the top learned 300 Ω as the maximum.
    - examples: 2 s settle gate after switch-on in the resistance template; sleep
    sampling window 2.5 s → 4.5 s; plausible_max: 250; 'Reset calibration' button.
    - tank_level: median window moved to RTC memory so it fill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
    [tank-common.yaml]
2026-09-08 hardware: rev 3 carrier PCB (55 x 52 mm, 4 layers) + updated hardware doc
    Adds the KiCad 10 project for the rev 3 carrier board under
    hardware/kali-tank-sensor-v3/: schematic and board generated from source
    (gen_sch.py, gen_pcb.py), custom symbols and footprints, gerbers, drill files,
    pick-and-place, BOM, and FABRICATION.md with the PCBWay order parameters,
    assembly order and the checks to run before first power-up. DRC 0 errors /
    0 unconnected, ERC 0 errors.
    Rev 3 vs the rev 2 breadboard build: bare INA238 with a 1 ohm 0.1 % shunt
    instead of the breakout's 15 mOhm, single 3.3 V rail from an 18x12 mm buck
    module, AO3400A instead of BS170, PTC + TVS + reverse diode on the 12 V input,
    I2C pul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
    [bom.csv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]
2026-09-13 examples: reduce log noise
    Drop the per-iBeacon debug line in the sleep package (it fired for every
    iBeacon heard, from any nearby device), log "OTA trigger matched" only on
    the first matching frame instead of every ~100 ms, and raise the ina2xx
    logger level to INFO to hide its per-second "Updating" lines.
    [tank-common.yaml]
